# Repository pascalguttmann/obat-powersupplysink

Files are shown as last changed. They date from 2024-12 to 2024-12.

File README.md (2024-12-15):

# Obat - PowerSupplySink

KiCAD Project for the PowerSupplySink.

| TOP | BOT |
| --- | --- |
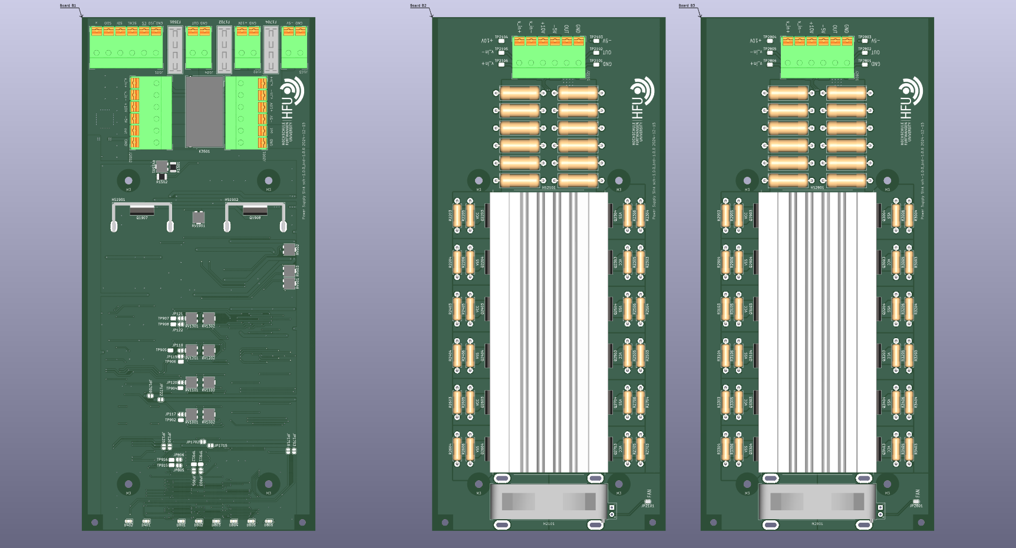
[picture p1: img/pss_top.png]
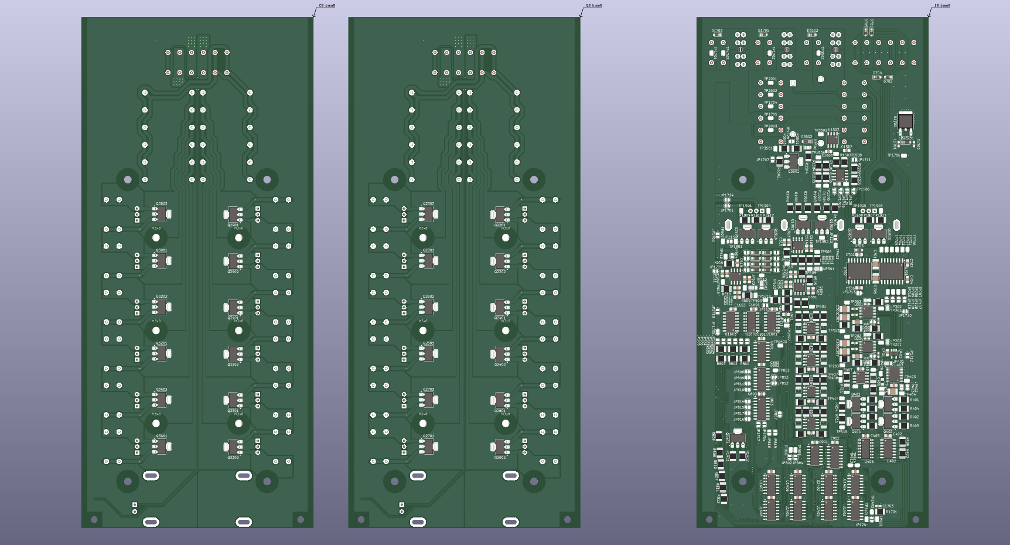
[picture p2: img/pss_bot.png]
|   |  |
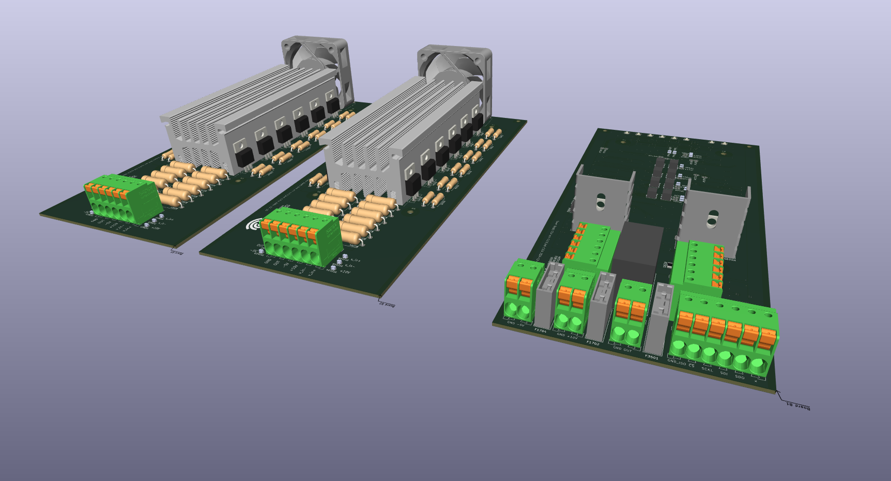
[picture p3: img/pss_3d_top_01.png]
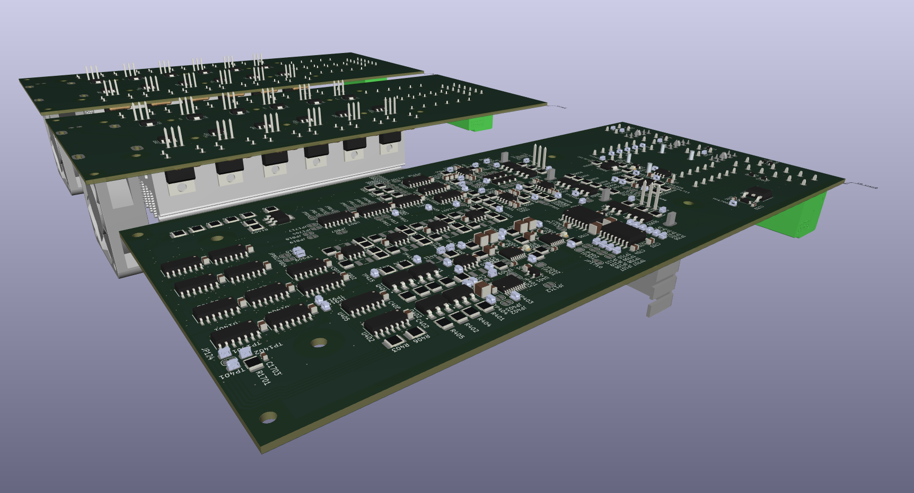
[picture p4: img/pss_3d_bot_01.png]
|  |  |
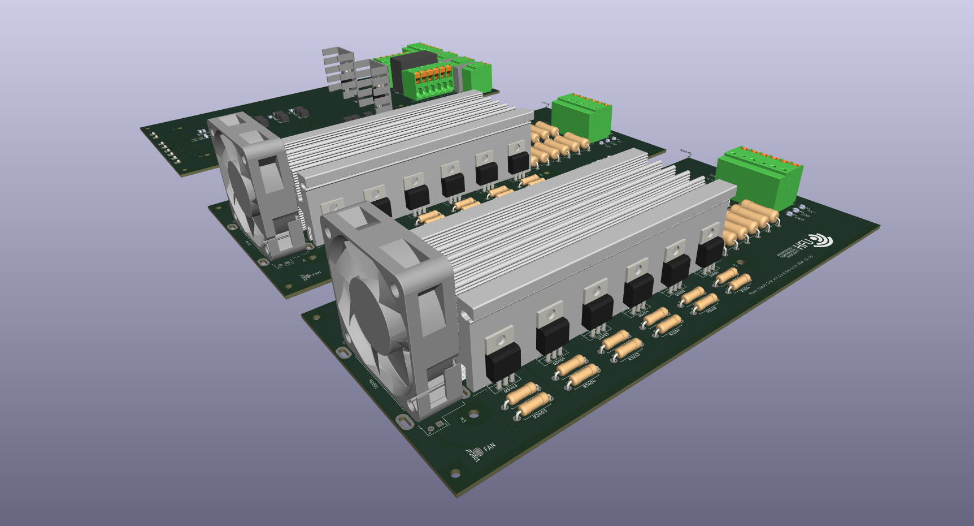
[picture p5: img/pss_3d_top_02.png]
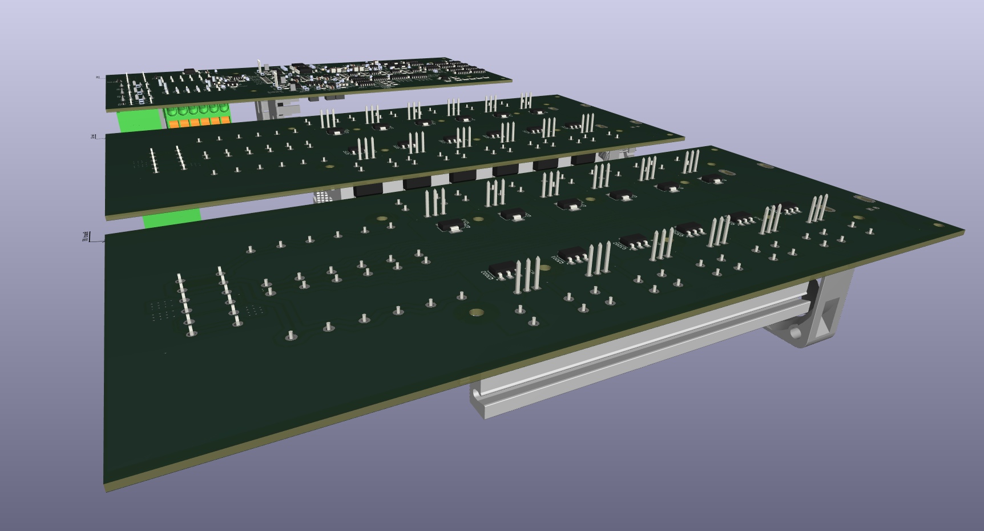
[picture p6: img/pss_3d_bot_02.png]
|  |  |

## License

This repository is licensed under the MIT license.

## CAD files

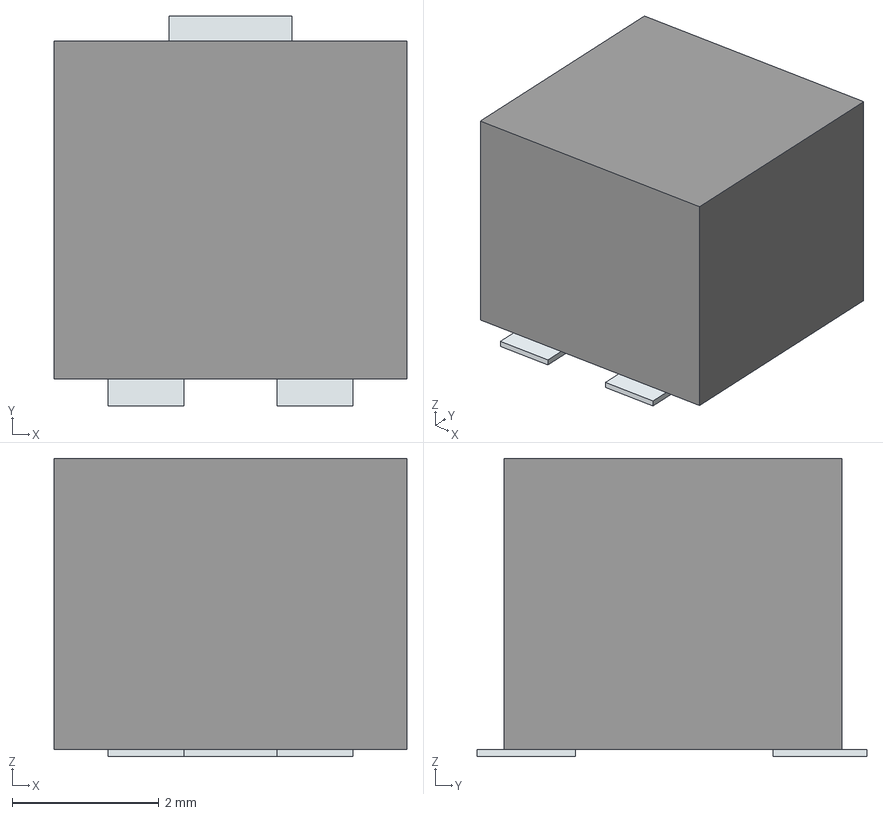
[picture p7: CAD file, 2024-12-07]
3d_models/PVG5H102C03R00.stp
4.80 x 5.31 x 4.06 mm
Pins

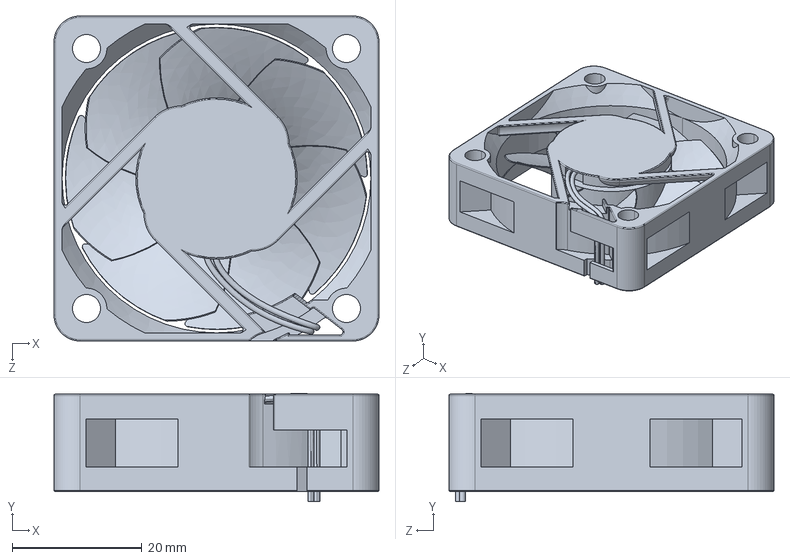
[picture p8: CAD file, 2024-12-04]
3d_models/Same_Sky_CFM-5015V-172-381.step
50.0 x 16.7 x 50.0 mm

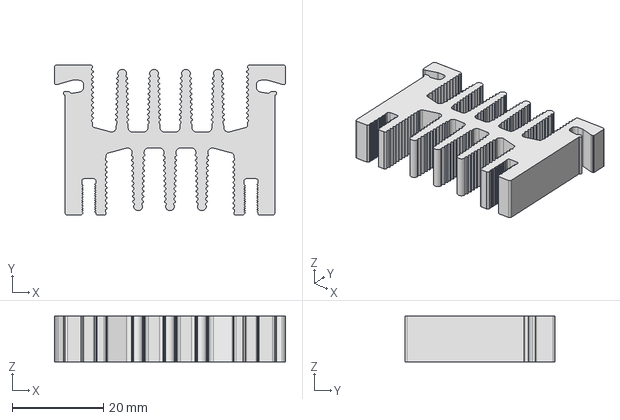
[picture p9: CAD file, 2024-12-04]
3d_models/sk499.stp
50.7 x 33.0 x 10.0 mm

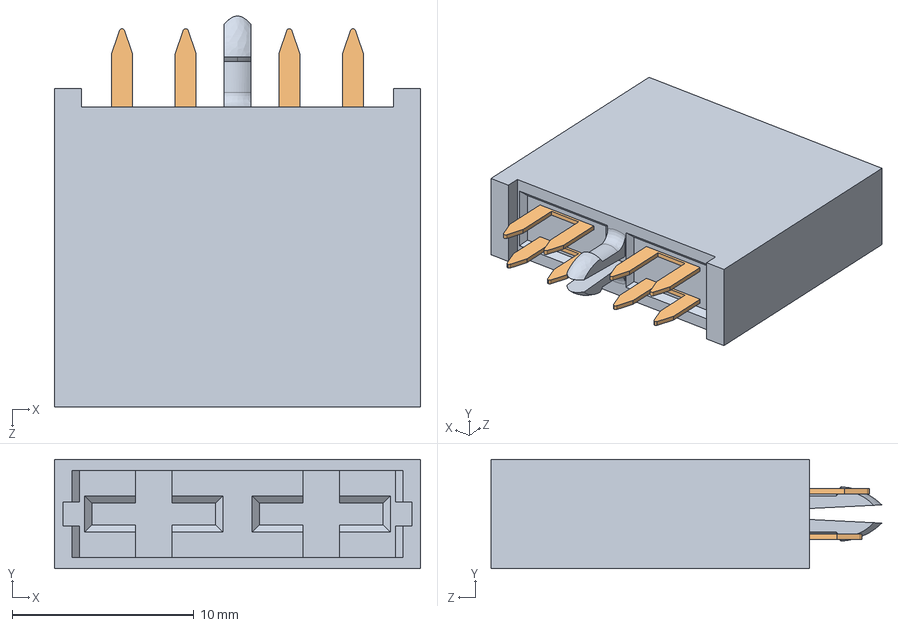
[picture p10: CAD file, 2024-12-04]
3d_models/178.6165.0000.step
20.1 x 6.00 x 21.5 mm

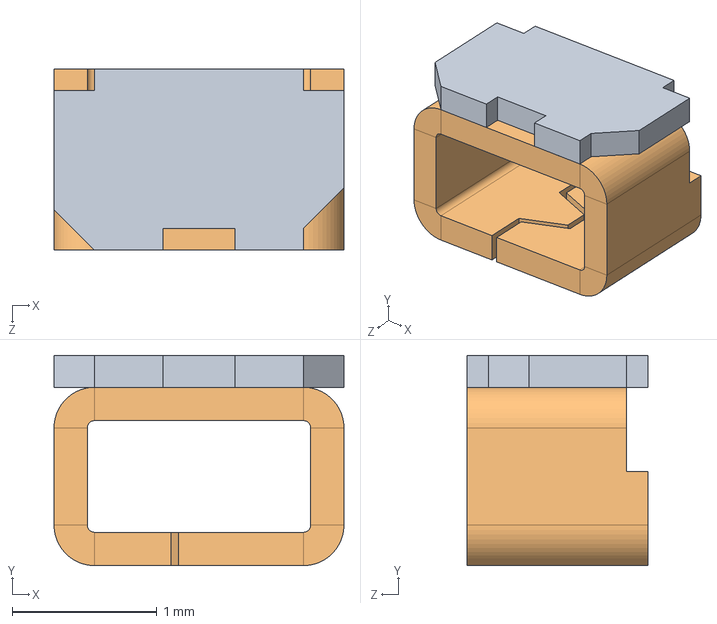
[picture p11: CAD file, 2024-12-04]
3d_models/RCTCTE.STEP
2.00 x 1.45 x 1.25 mm

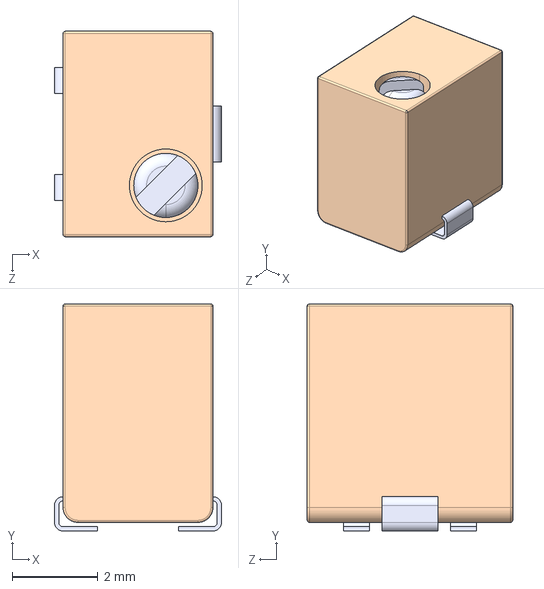
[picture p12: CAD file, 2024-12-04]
3d_models/PVG5A102C03B00.step
3.90 x 5.30 x 4.80 mm

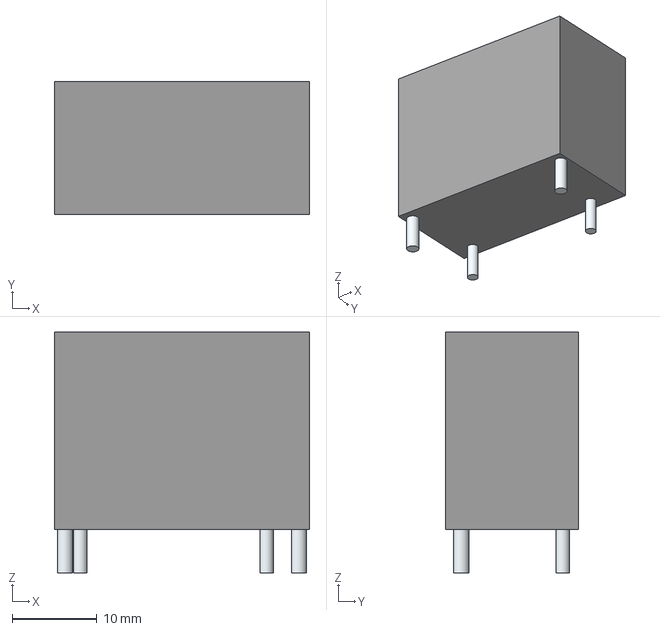
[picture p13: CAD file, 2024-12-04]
3d_models/ALFG2PF12.stp
30.1 x 15.7 x 28.4 mm
Leads x 4

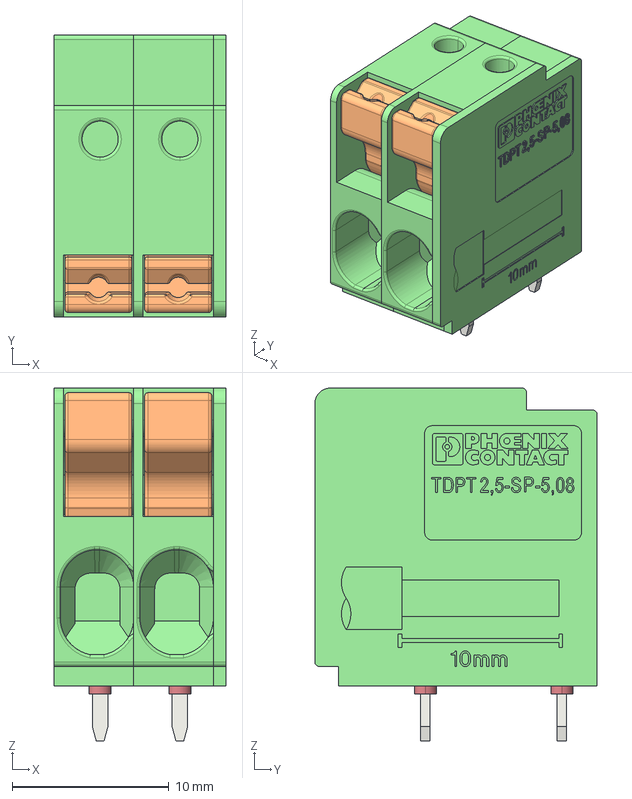
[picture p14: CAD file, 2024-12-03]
3d_models/pxc_1017503_00_00_TDPT-2-5-2-SP-5-08_3D.stp
11.0 x 18.0 x 22.5 mm
Bohrloch x 4
LP_TDPT_2_5_SP_DRST_vorne x 2
LP_TDPT_2_5_SP_DRST_hinten x 2
AC_TDPT_2_5_SP_pusher x 2
PK_TDPT_2_5_SP_GEH
PK_TDPT_2_5_SP_ENDGEH
DK_TDPT_2_5_SP

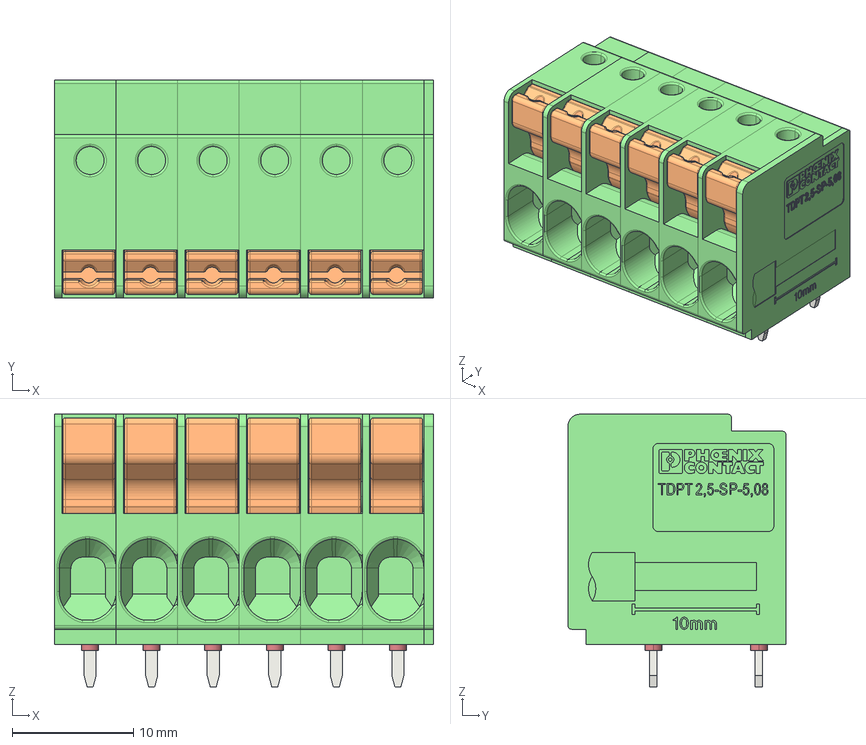
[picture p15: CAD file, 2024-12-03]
3d_models/pxc_1017507_00_00_TDPT-2-5-6-SP-5-08_3D.stp
31.3 x 18.0 x 22.5 mm
Bohrloch.2 x 12
LP_TDPT_2_5_SP_DRST_vorne.1 x 6
LP_TDPT_2_5_SP_DRST_hinten x 6
AC_TDPT_2_5_SP_pusher.1 x 6
PK_TDPT_2_5_SP_GEH x 5
PK_TDPT_2_5_SP_ENDGEH
DK_TDPT_2_5_SP

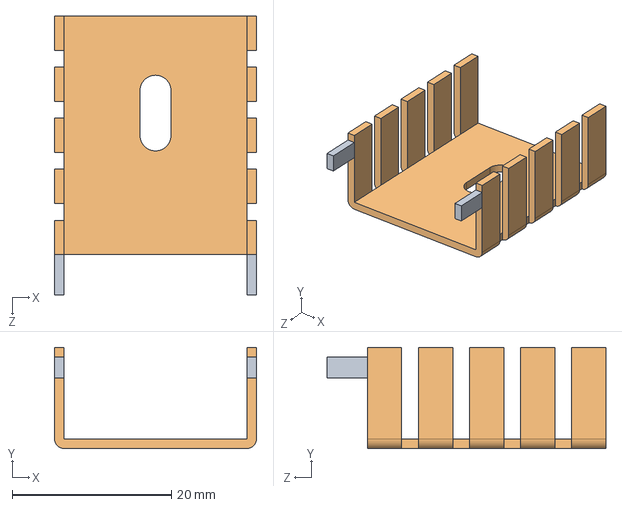
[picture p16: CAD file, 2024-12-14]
3d_models/575002B00000G.stp
25.4 x 12.7 x 35.0 mm

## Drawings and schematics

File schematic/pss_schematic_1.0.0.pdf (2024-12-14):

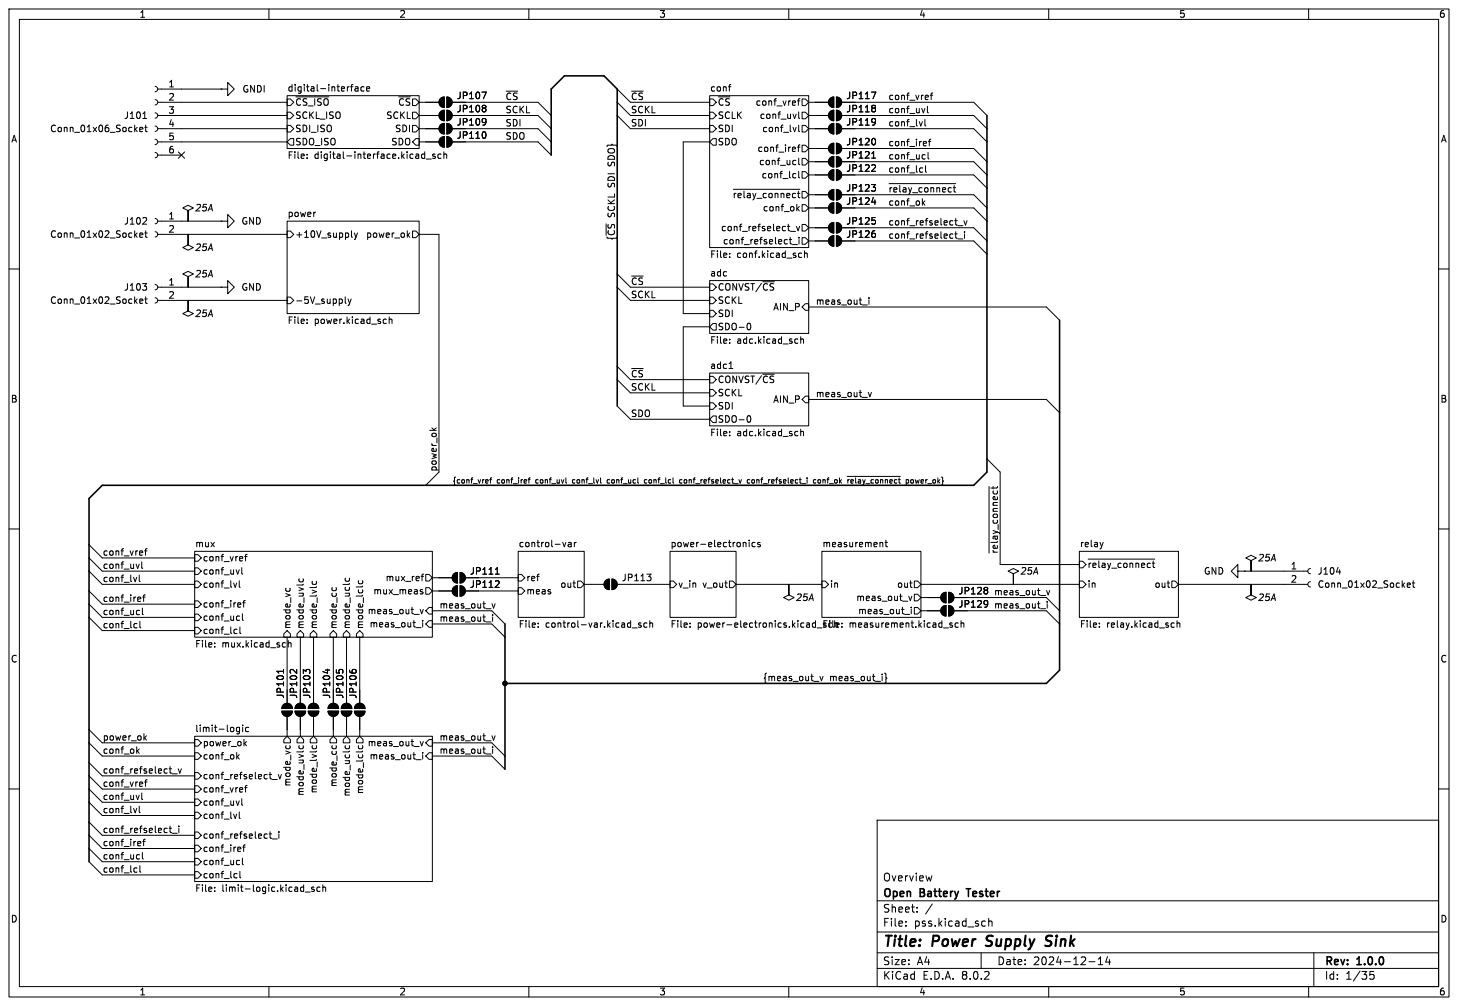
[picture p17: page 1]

SCKL SDI digital-interface File: digital-interface.kicad_sch
~{CS_ISO} SDI_ISO
SCKL_ISO

adc1 File: adc.kicad_sch AIN_P SDI CONVST/~{CS} SCKL SDO-0

ref control-var File: control-var.kicad_sch

v_in v_out power-electronics File: power-electronics.kicad_sch

limit-logic File: limit-logic.kicad_sch
conf_ok power_ok

Id: 1/35 Title: Power Supply Sink

3 REFIO 4 REFGND 5 REFCAP 6 AIN_P 7 AIN_GND 8 ~{RST} 9 GND GND GND

3 REFIO 4 REFGND 5 REFCAP 6 AIN_P 7 AIN_GND 8 ~{RST} 9 U201 ADS8665IPWR GND

1 SDI 10 CONVST/~{CS} 11 SCKL 12 SDO-0 13 ALARM/SDO-1/GPO 14 RVS 15 DVDD 16 AVDD

Id: 2/35 Title: Power Supply Sink

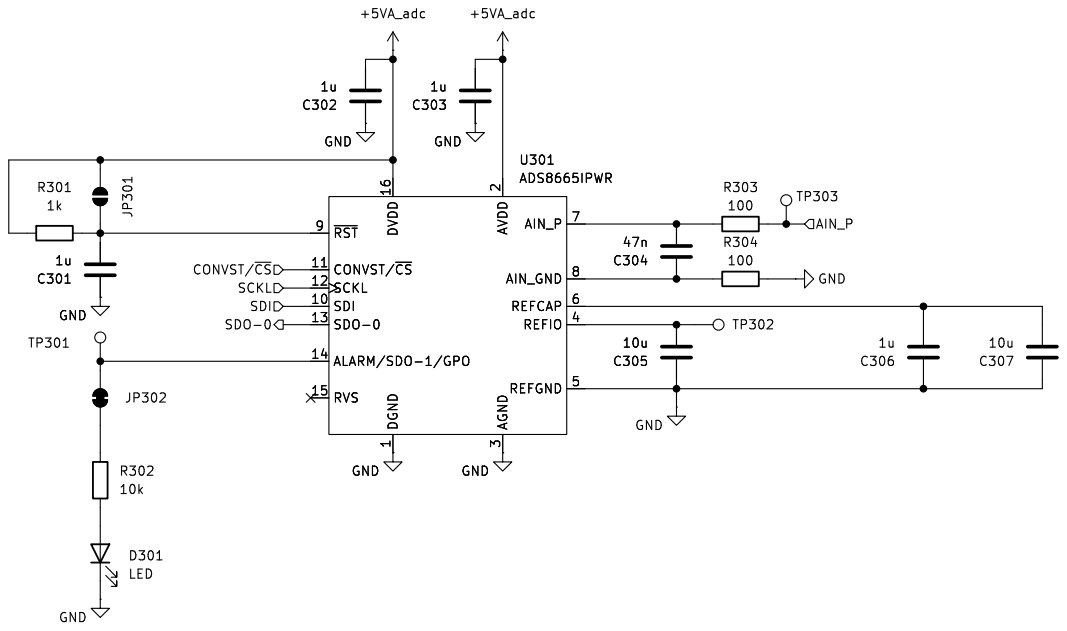
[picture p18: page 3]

3 REFIO 4 REFGND 5 REFCAP 6 AIN_P 7 AIN_GND 8 ~{RST} 9 GND GND

3 REFIO 4 REFGND 5 REFCAP 6 AIN_P 7 AIN_GND 8 ~{RST} 9 U301 ADS8665IPWR R303

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

Id: 3/35 Title: Power Supply Sink

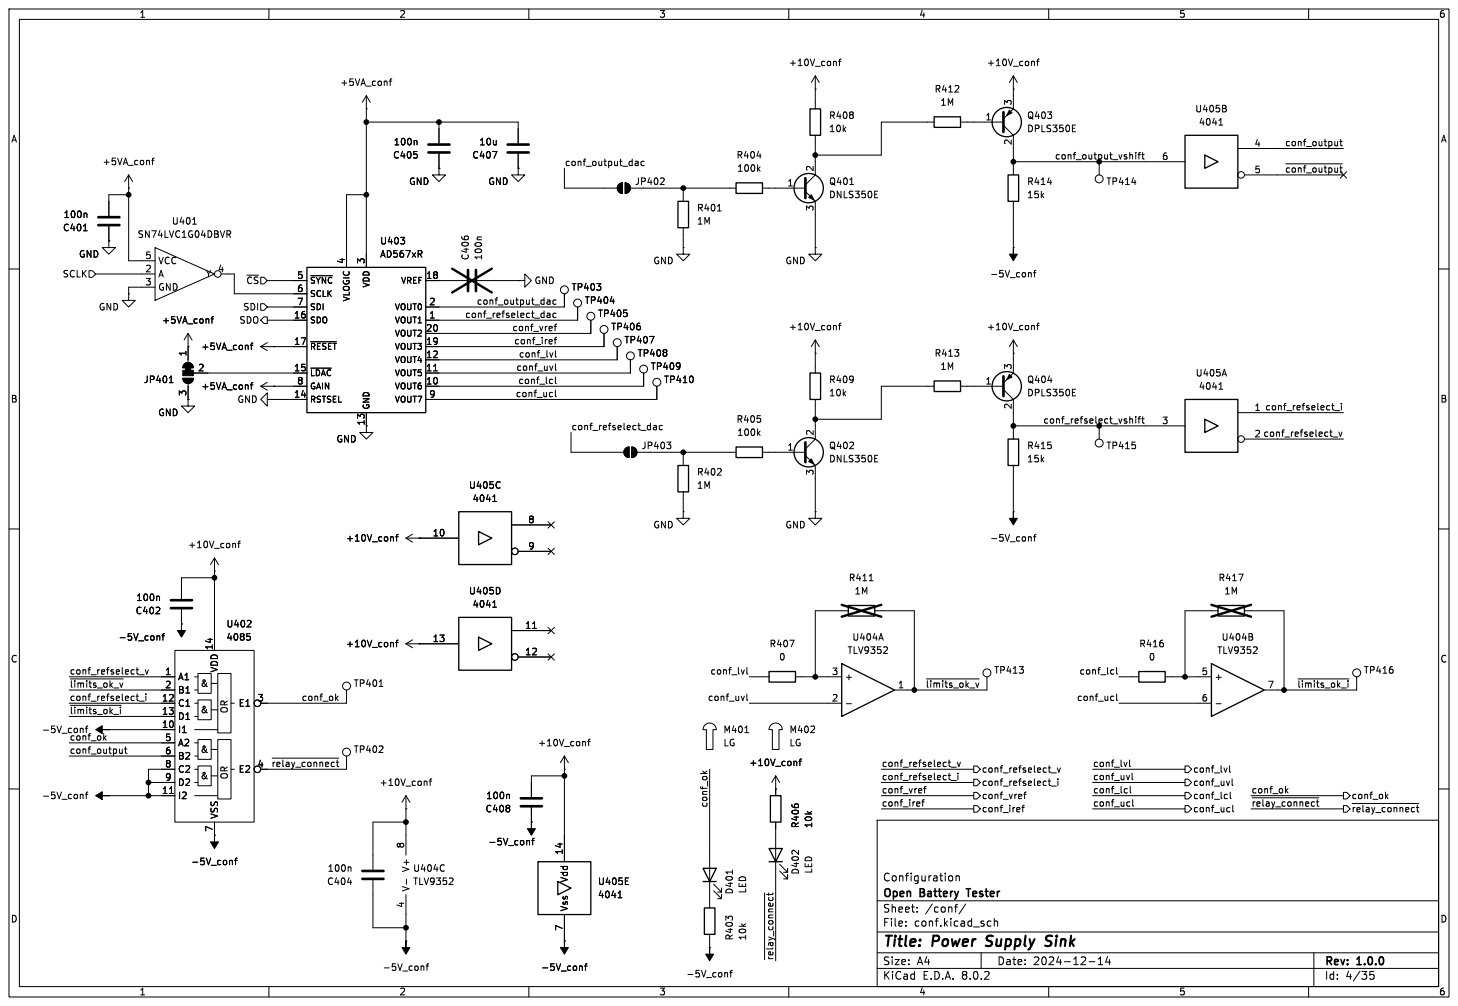
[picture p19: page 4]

Id: 4/35 Title: Power Supply Sink

diode-network File: diode-network.kicad_sch C518

Id: 5/35 Title: Power Supply Sink

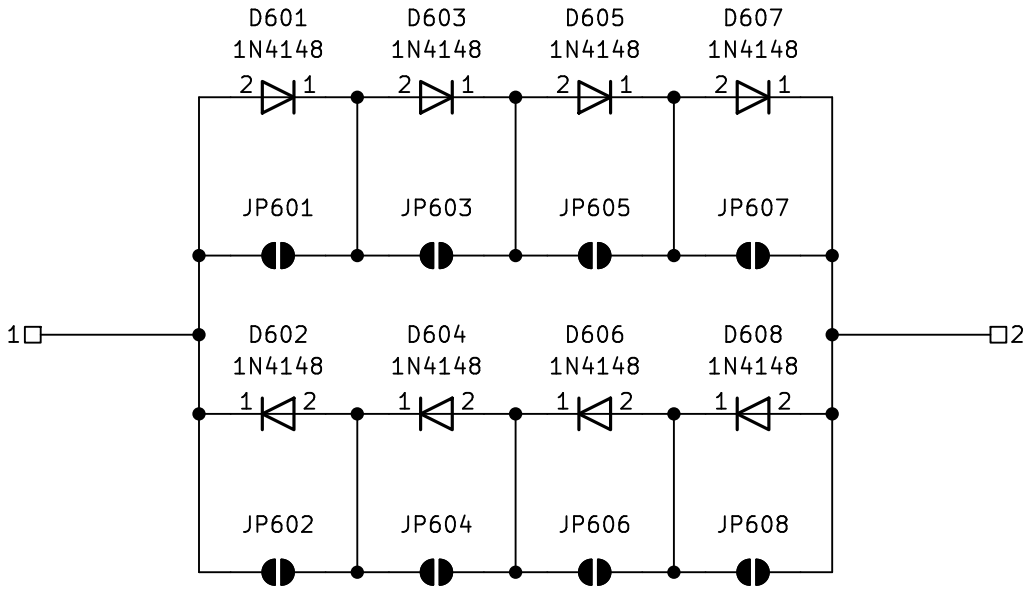
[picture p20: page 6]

Id: 6/35 Title: Power Supply Sink

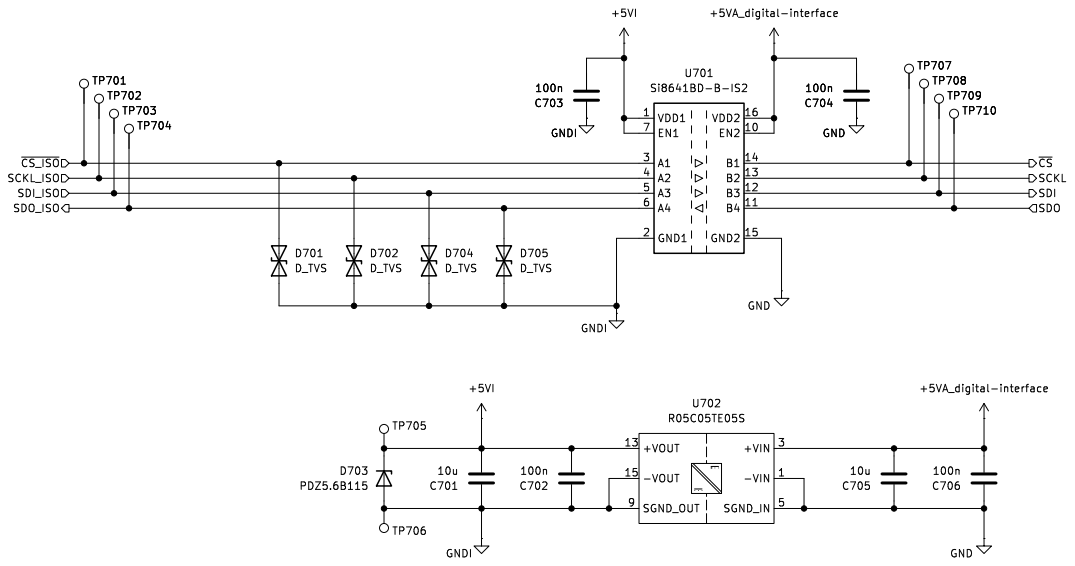
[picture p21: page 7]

File: digital-interface.kicad_sch Sheet: /digital-interface/
Id: 7/35 Title: Power Supply Sink

conf_refselect_i comp_mgtt comp_mstt mode-transition File: mode-transition.kicad_sch

conf_refselect_i compare-logic File: compare-logic.kicad_sch

File: limit-logic.kicad_sch Sheet: /limit-logic/
Id: 8/35 Title: Power Supply Sink

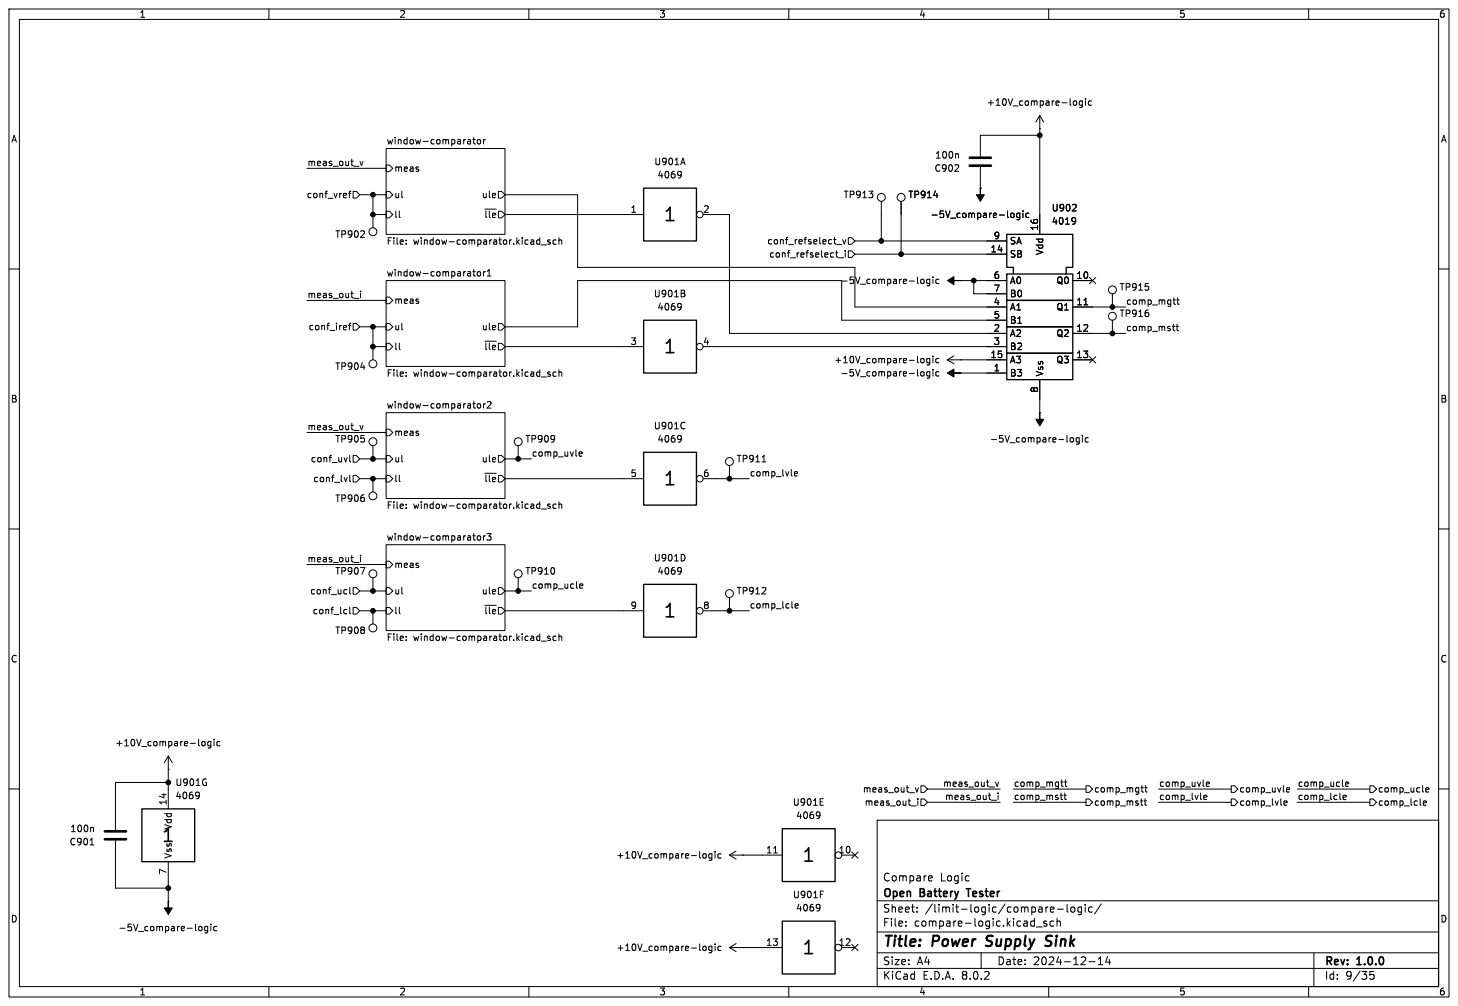
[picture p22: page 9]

llul window-comparator File: window-comparator.kicad_sch

llul window-comparator1 File: window-comparator.kicad_sch

llul window-comparator2 File: window-comparator.kicad_sch

llul window-comparator3 File: window-comparator.kicad_sch

File: compare-logic.kicad_sch Sheet: /limit-logic/compare-logic/
Id: 9/35 Title: Power Supply Sink

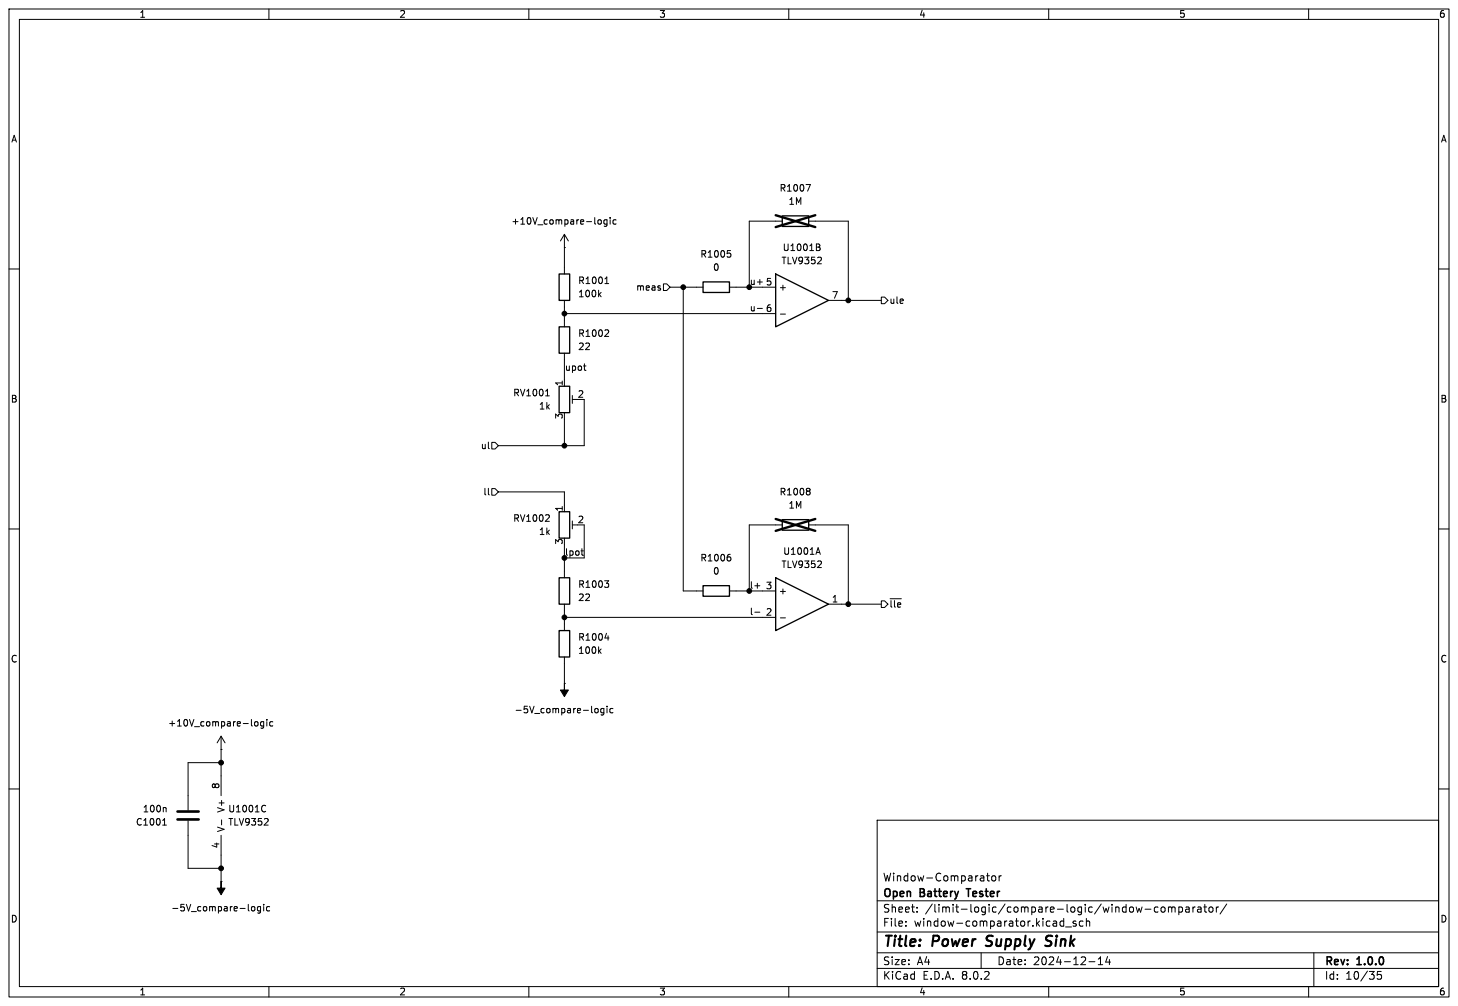
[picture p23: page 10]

File: window-comparator.kicad_sch Sheet: /limit-logic/compare-logic/window-comparator/
Id: 10/35 Title: Power Supply Sink

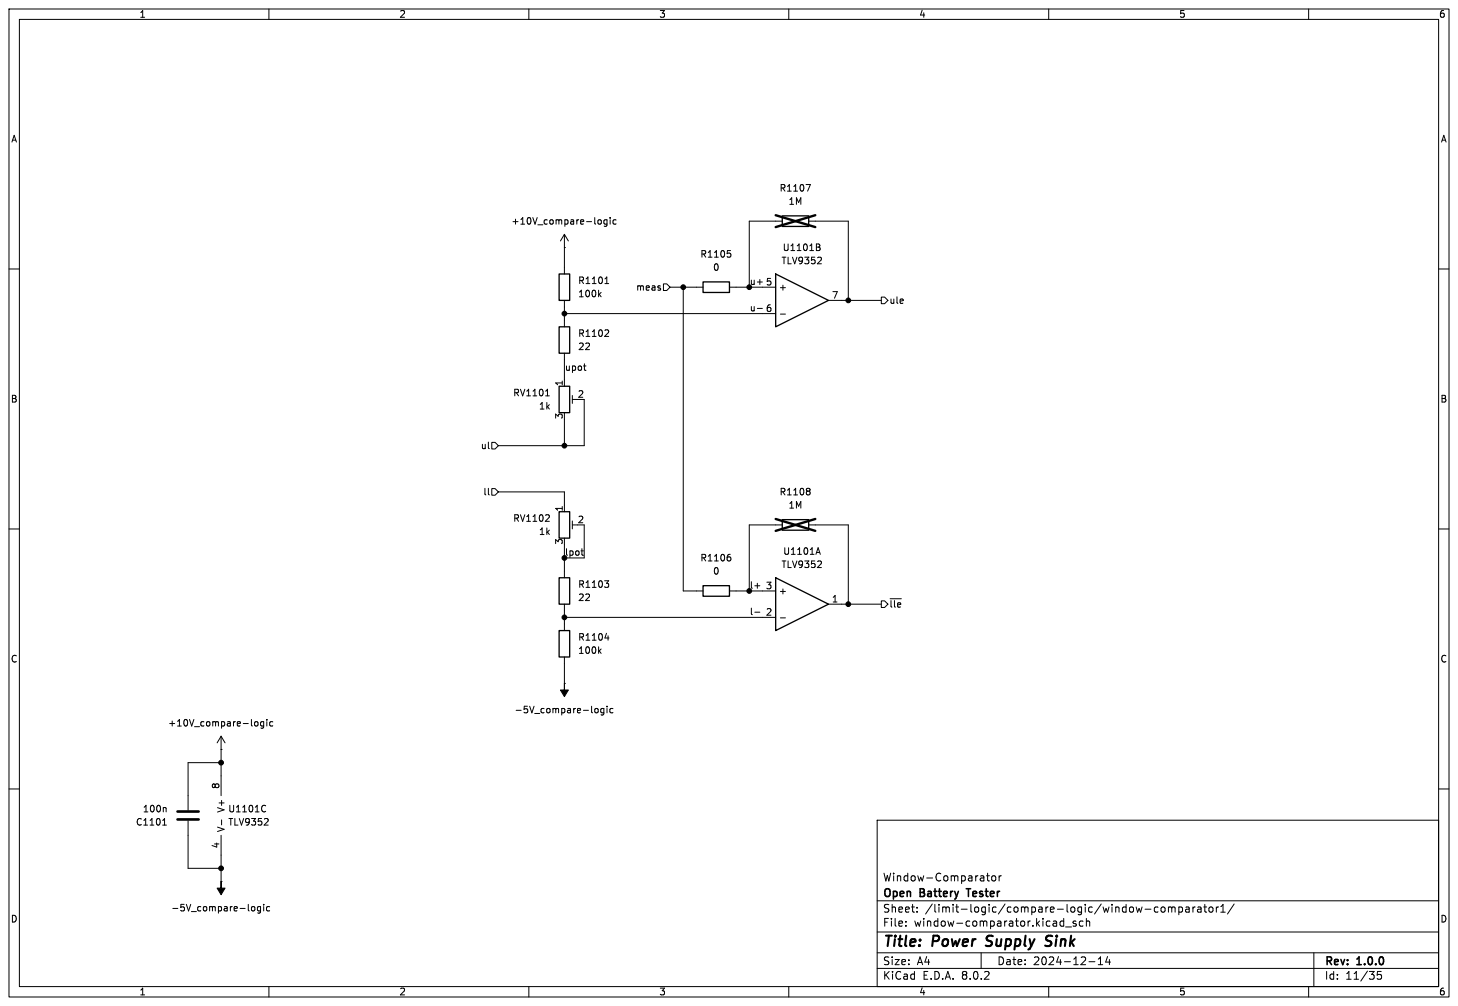
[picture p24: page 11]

File: window-comparator.kicad_sch Sheet: /limit-logic/compare-logic/window-comparator1/
Id: 11/35 Title: Power Supply Sink

File: window-comparator.kicad_sch Sheet: /limit-logic/compare-logic/window-comparator2/
Id: 12/35 Title: Power Supply Sink

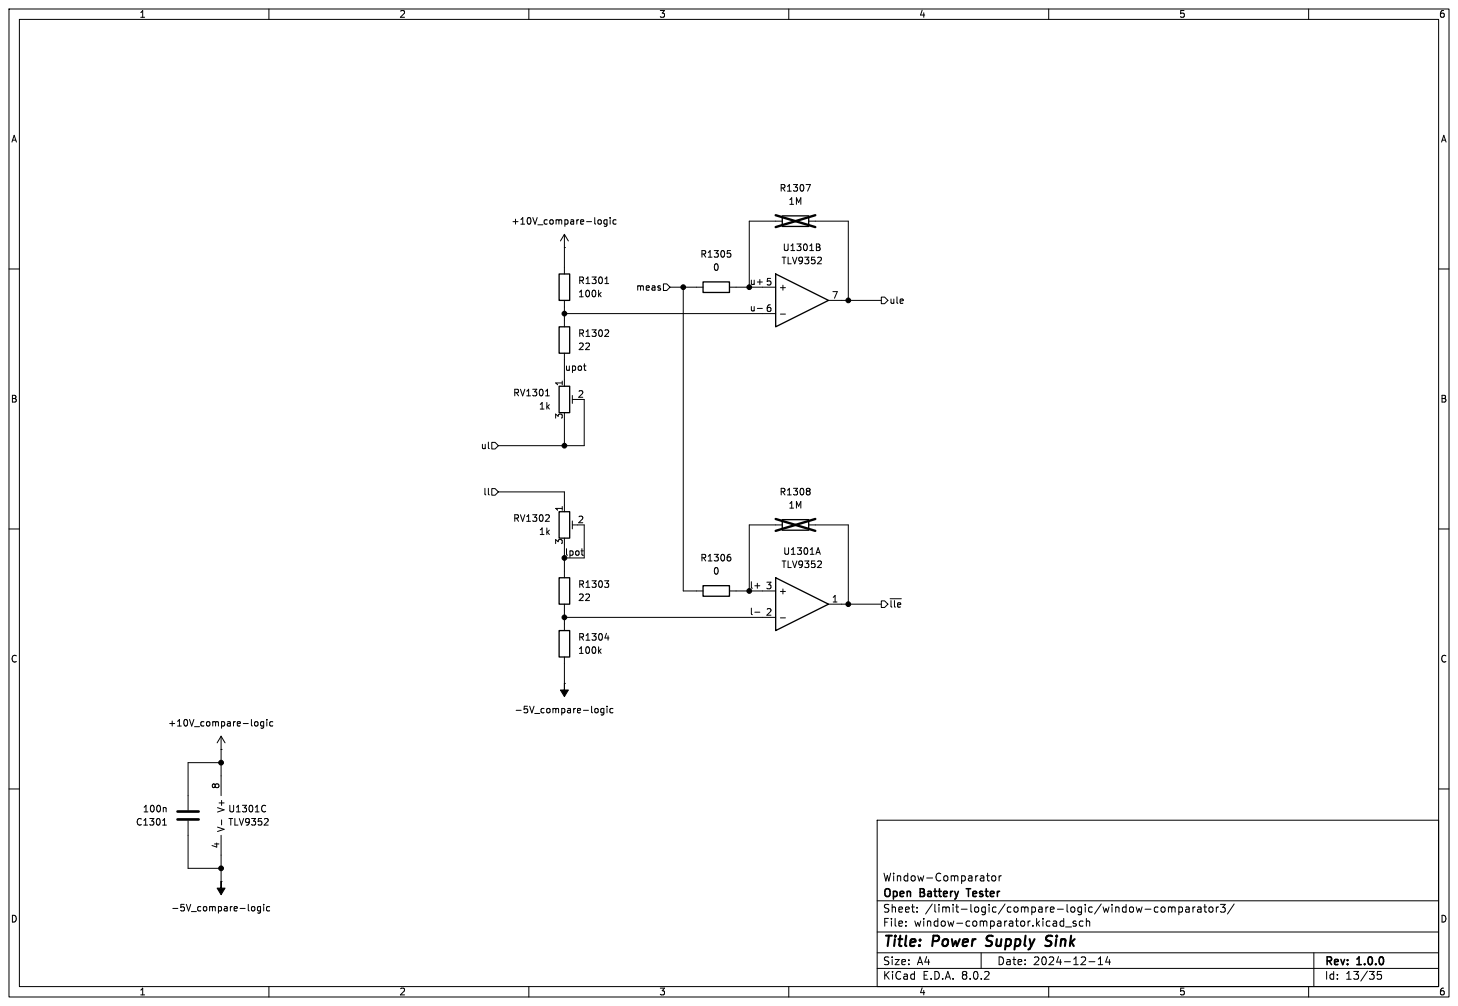
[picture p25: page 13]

File: window-comparator.kicad_sch Sheet: /limit-logic/compare-logic/window-comparator3/
Id: 13/35 Title: Power Supply Sink

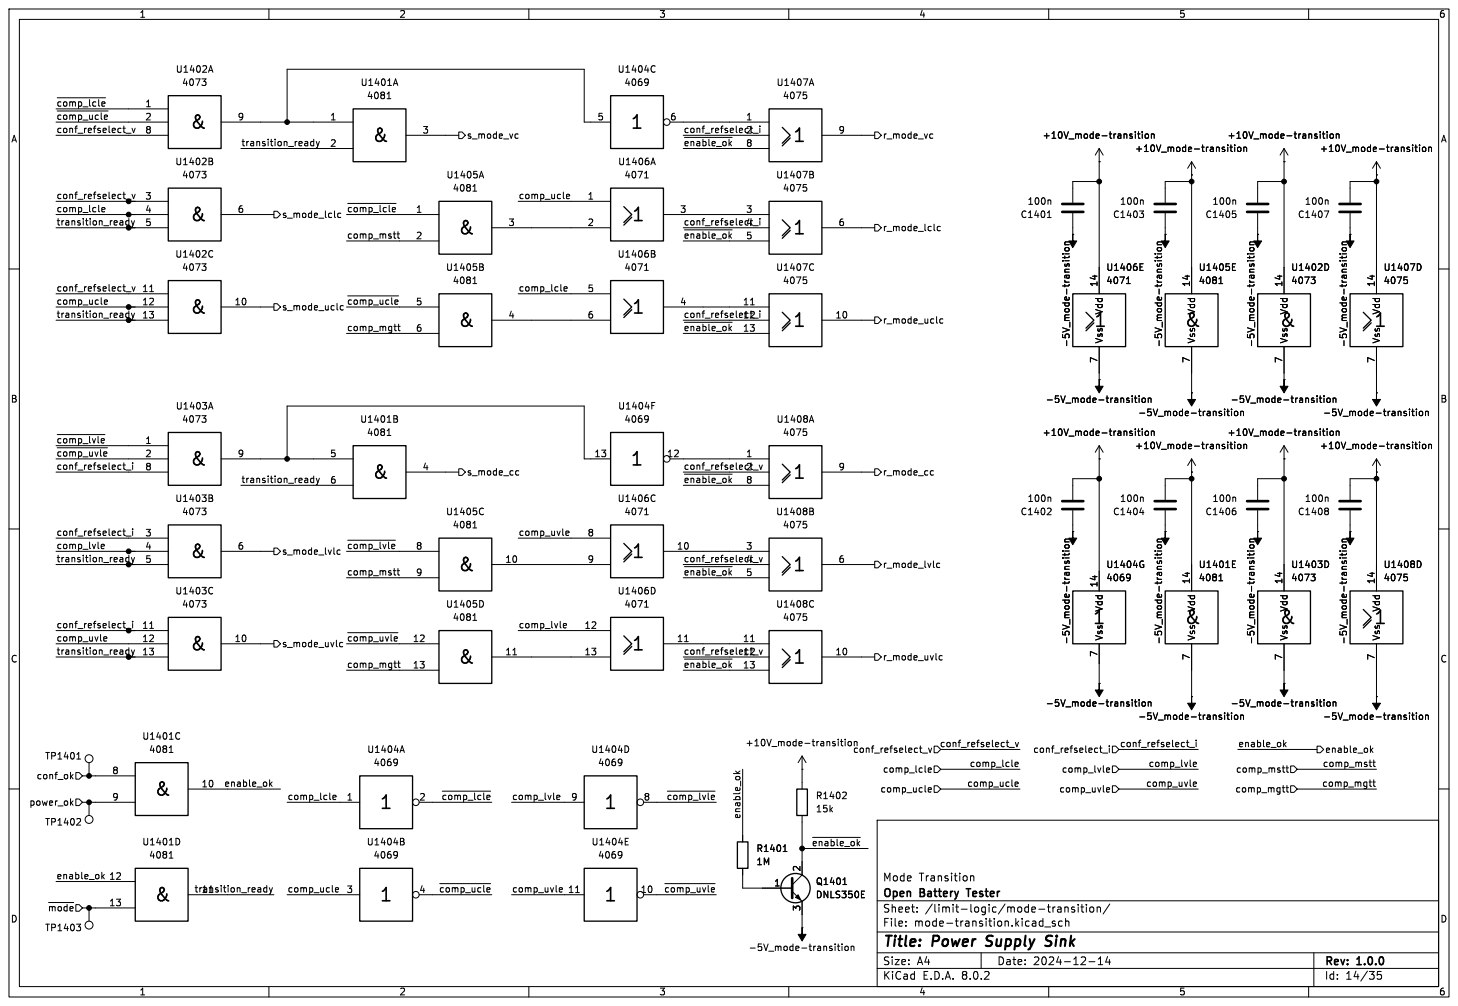
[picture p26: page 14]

File: mode-transition.kicad_sch Sheet: /limit-logic/mode-transition/
Id: 14/35 Title: Power Supply Sink

Id: 15/35 Title: Power Supply Sink

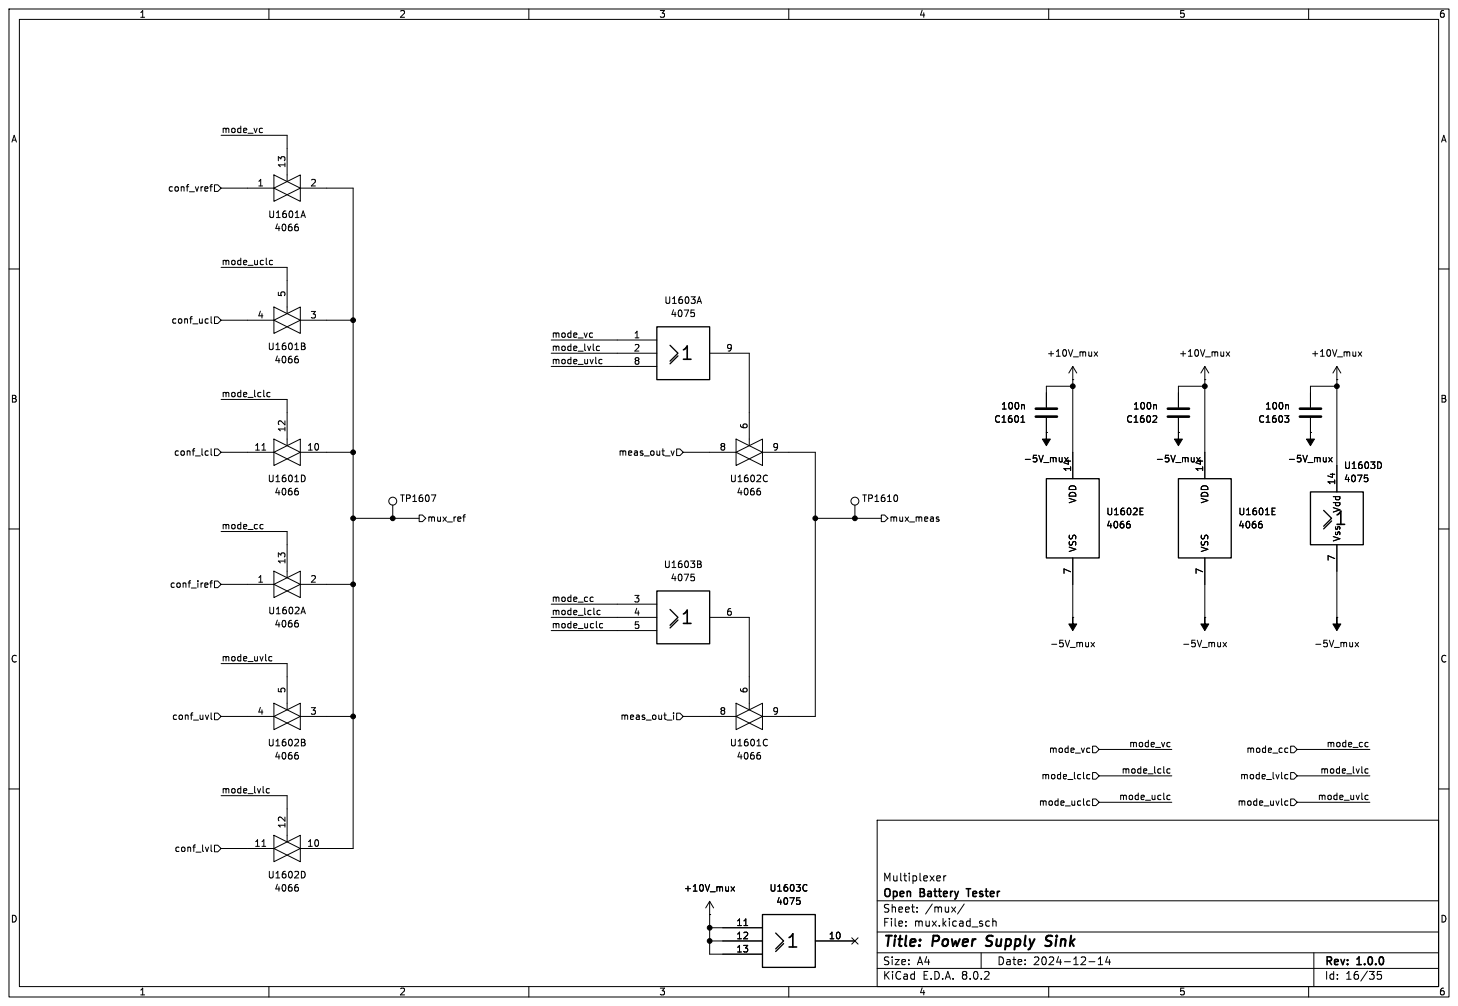
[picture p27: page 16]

Id: 16/35 Title: Power Supply Sink

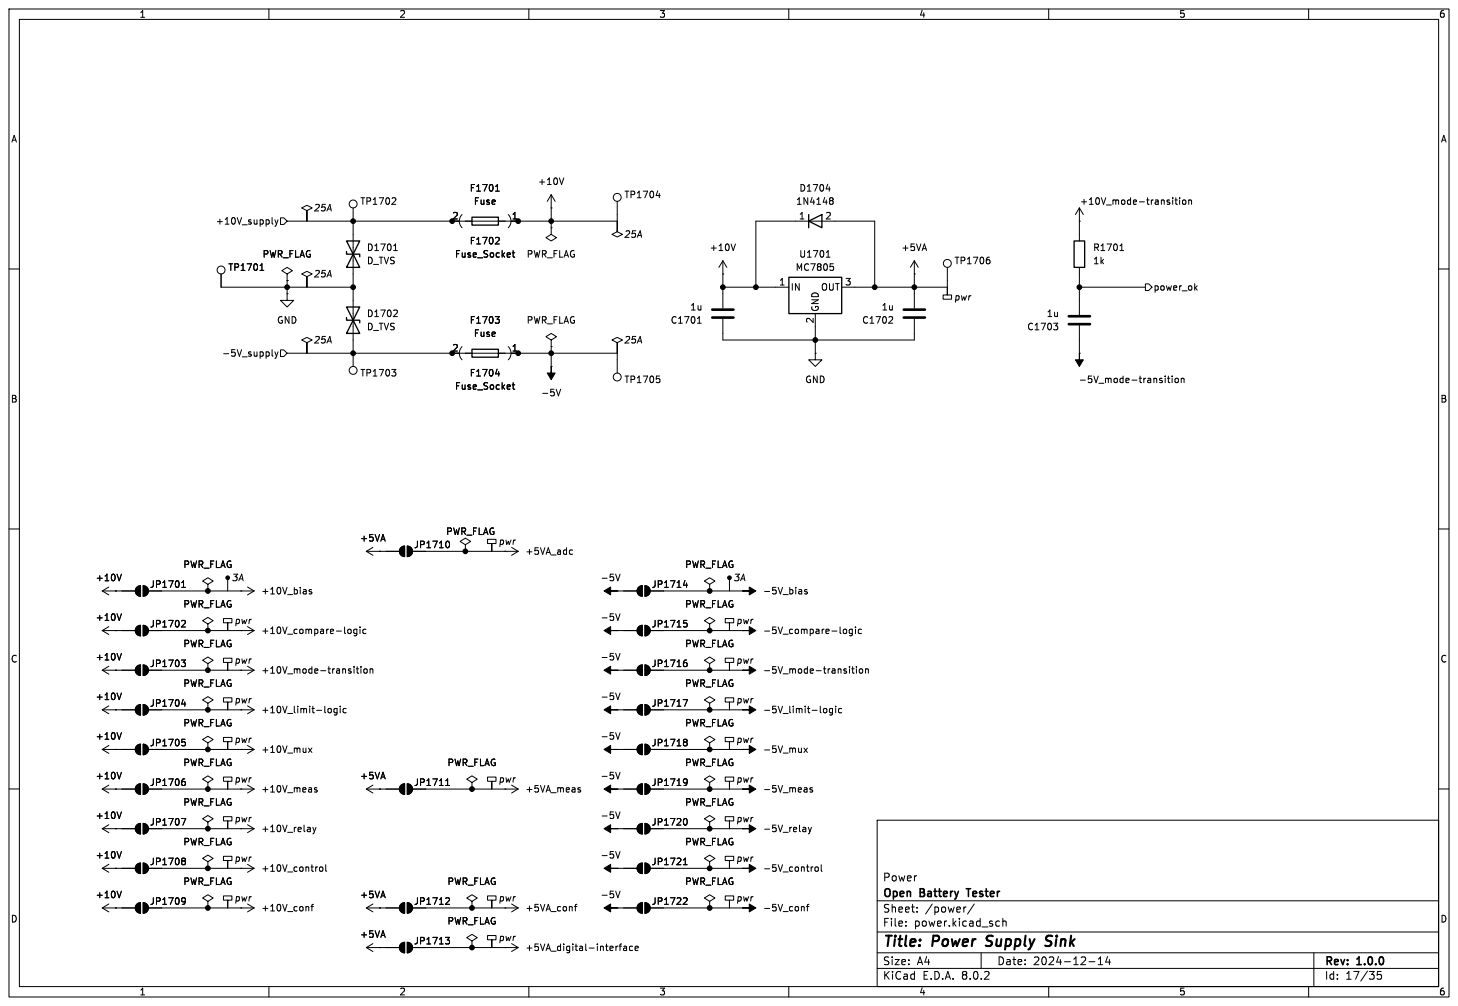
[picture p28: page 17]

File: power.kicad_sch Sheet: /power/
Id: 17/35 Title: Power Supply Sink

File: power-electronics.kicad_sch Sheet: /power-electronics/
Id: 18/35 Title: Power Supply Sink


File: bias.kicad_sch Sheet: /power-electronics/bias/
Id: 19/35 Title: Power Supply Sink


File: outstage.kicad_sch Sheet: /power-electronics/outstage/
Id: 20/35 Title: Power Supply Sink

File: outstage-unit.kicad_sch Sheet: /power-electronics/outstage/outstage-unit/
Id: 21/35 Title: Power Supply Sink


File: emitter_follower.kicad_sch Sheet: /power-electronics/outstage/outstage-unit/emitter_follower1/
Id: 22/35 Title: Power Supply Sink


File: emitter_follower.kicad_sch Sheet: /power-electronics/outstage/outstage-unit/emitter_follower2/
Id: 23/35 Title: Power Supply Sink

File: emitter_follower.kicad_sch Sheet: /power-electronics/outstage/outstage-unit/emitter_follower3/
Id: 24/35 Title: Power Supply Sink


File: emitter_follower.kicad_sch Sheet: /power-electronics/outstage/outstage-unit/emitter_follower4/
Id: 25/35 Title: Power Supply Sink


File: emitter_follower.kicad_sch Sheet: /power-electronics/outstage/outstage-unit/emitter_follower5/
Id: 26/35 Title: Power Supply Sink


File: emitter_follower.kicad_sch Sheet: /power-electronics/outstage/outstage-unit/emitter_follower6/
Id: 27/35 Title: Power Supply Sink

File: outstage-unit.kicad_sch Sheet: /power-electronics/outstage/outstage-unit1/
Id: 28/35 Title: Power Supply Sink


File: emitter_follower.kicad_sch Sheet: /power-electronics/outstage/outstage-unit1/emitter_follower1/
Id: 29/35 Title: Power Supply Sink

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

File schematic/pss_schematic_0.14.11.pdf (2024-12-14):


SCKL SDI digital-interface File: digital-interface.kicad_sch
~{CS_ISO} SDI_ISO
SCKL_ISO

adc1 File: adc.kicad_sch AIN_P SDI CONVST/~{CS} SCKL SDO-0

ref control-var File: control-var.kicad_sch

v_in v_out power-electronics File: power-electronics.kicad_sch

limit-logic File: limit-logic.kicad_sch
conf_ok power_ok

Id: 1/35 Title: Power Supply Sink

3 REFIO 4 REFGND 5 REFCAP 6 AIN_P 7 AIN_GND 8 ~{RST} 9 U201 ADS8665IPWR GND

1 SDI 10 CONVST/~{CS} 11 SCKL 12 SDO-0 13 ALARM/SDO-1/GPO 14 RVS 15 DVDD 16 AVDD

3 REFIO 4 REFGND 5 REFCAP 6 AIN_P 7 AIN_GND 8 ~{RST} 9 GND

Id: 2/35 Title: Power Supply Sink


3 REFIO 4 REFGND 5 REFCAP 6 AIN_P 7 AIN_GND 8 ~{RST} 9 U301 ADS8665IPWR

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

3 REFIO 4 REFGND 5 REFCAP 6 AIN_P 7 AIN_GND 8 ~{RST} 9 GND

Id: 3/35 Title: Power Supply Sink


Id: 4/35 Title: Power Supply Sink

diode-network File: diode-network.kicad_sch R510

Id: 5/35 Title: Power Supply Sink


Id: 6/35 Title: Power Supply Sink


File: digital-interface.kicad_sch Sheet: /digital-interface/
Id: 7/35 Title: Power Supply Sink

conf_refselect_i comp_mgtt comp_mstt mode-transition File: mode-transition.kicad_sch
s_mode_cc enable_ok

conf_refselect_i compare-logic File: compare-logic.kicad_sch

File: limit-logic.kicad_sch Sheet: /limit-logic/
Id: 8/35 Title: Power Supply Sink


llul window-comparator File: window-comparator.kicad_sch C901

llul window-comparator1 File: window-comparator.kicad_sch

llul window-comparator2 File: window-comparator.kicad_sch

llul window-comparator3 File: window-comparator.kicad_sch

File: compare-logic.kicad_sch Sheet: /limit-logic/compare-logic/
Id: 9/35 Title: Power Supply Sink


File: window-comparator.kicad_sch Sheet: /limit-logic/compare-logic/window-comparator/
Id: 10/35 Title: Power Supply Sink


File: window-comparator.kicad_sch Sheet: /limit-logic/compare-logic/window-comparator1/
Id: 11/35 Title: Power Supply Sink

File: window-comparator.kicad_sch Sheet: /limit-logic/compare-logic/window-comparator2/
Id: 12/35 Title: Power Supply Sink


File: window-comparator.kicad_sch Sheet: /limit-logic/compare-logic/window-comparator3/
Id: 13/35 Title: Power Supply Sink


4075 Vdd 14 Vss 7 +10V_mode-transition +10V_mode-transition

File: mode-transition.kicad_sch Sheet: /limit-logic/mode-transition/
Id: 14/35 Title: Power Supply Sink

Id: 15/35 Title: Power Supply Sink


Id: 16/35 Title: Power Supply Sink


File: power.kicad_sch Sheet: /power/
Id: 17/35 Title: Power Supply Sink

File: power-electronics.kicad_sch Sheet: /power-electronics/
Id: 18/35 Title: Power Supply Sink


File: bias.kicad_sch Sheet: /power-electronics/bias/
Id: 19/35 Title: Power Supply Sink


File: outstage.kicad_sch Sheet: /power-electronics/outstage/
Id: 20/35 Title: Power Supply Sink

File: outstage-unit.kicad_sch Sheet: /power-electronics/outstage/outstage-unit/
Id: 21/35 Title: Power Supply Sink


File: emitter_follower.kicad_sch Sheet: /power-electronics/outstage/outstage-unit/emitter_follower1/
Id: 22/35 Title: Power Supply Sink


File: emitter_follower.kicad_sch Sheet: /power-electronics/outstage/outstage-unit/emitter_follower2/
Id: 23/35 Title: Power Supply Sink

File: emitter_follower.kicad_sch Sheet: /power-electronics/outstage/outstage-unit/emitter_follower3/
Id: 24/35 Title: Power Supply Sink


File: emitter_follower.kicad_sch Sheet: /power-electronics/outstage/outstage-unit/emitter_follower4/
Id: 25/35 Title: Power Supply Sink


File: emitter_follower.kicad_sch Sheet: /power-electronics/outstage/outstage-unit/emitter_follower5/
Id: 26/35 Title: Power Supply Sink


File: emitter_follower.kicad_sch Sheet: /power-electronics/outstage/outstage-unit/emitter_follower6/
Id: 27/35 Title: Power Supply Sink

File: outstage-unit.kicad_sch Sheet: /power-electronics/outstage/outstage-unit1/
Id: 28/35 Title: Power Supply Sink


File: emitter_follower.kicad_sch Sheet: /power-electronics/outstage/outstage-unit1/emitter_follower1/
Id: 29/35 Title: Power Supply Sink

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

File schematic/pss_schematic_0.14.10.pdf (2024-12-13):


SCKL SDI digital-interface File: digital-interface.kicad_sch
~{CS_ISO} SDI_ISO
SCKL_ISO

adc1 File: adc.kicad_sch AIN_P SDI CONVST/~{CS} SCKL SDO-0

ref control-var File: control-var.kicad_sch

v_in v_out power-electronics File: power-electronics.kicad_sch

limit-logic File: limit-logic.kicad_sch
conf_ok power_ok

Id: 1/35 Title: Power Supply Sink

3 REFIO 4 REFGND 5 REFCAP 6 AIN_P 7 AIN_GND 8 ~{RST} 9GND

3 REFIO 4 REFGND 5 REFCAP 6 AIN_P 7 AIN_GND 8 ~{RST} 9 U201 ADS8665IPWR

1 SDI 10 CONVST/~{CS} 11 SCKL 12 SDO-0 13 ALARM/SDO-1/GPO 14 RVS 15 DVDD 16 AVDD

Id: 2/35 Title: Power Supply Sink


3 REFIO 4 REFGND 5 REFCAP 6 AIN_P 7 AIN_GND 8 ~{RST} 9 U301 ADS8665IPWR GND GND

3 REFIO 4 REFGND 5 REFCAP 6 AIN_P 7 AIN_GND 8 ~{RST} 9 GND GND

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

Id: 3/35 Title: Power Supply Sink


Id: 4/35 Title: Power Supply Sink

diode-network File: diode-network.kicad_sch R510

Id: 5/35 Title: Power Supply Sink


Id: 6/35 Title: Power Supply Sink


File: digital-interface.kicad_sch Sheet: /digital-interface/
Id: 7/35 Title: Power Supply Sink

conf_refselect_i compare-logic File: compare-logic.kicad_sch
conf_vref conf_refselect_v

File: limit-logic.kicad_sch Sheet: /limit-logic/
Id: 8/35 Title: Power Supply Sink


llul window-comparator File: window-comparator.kicad_sch

llul window-comparator1 File: window-comparator.kicad_sch

llul window-comparator2 File: window-comparator.kicad_sch

llul window-comparator3 File: window-comparator.kicad_sch

File: compare-logic.kicad_sch Sheet: /limit-logic/compare-logic/
Id: 9/35 Title: Power Supply Sink


File: window-comparator.kicad_sch Sheet: /limit-logic/compare-logic/window-comparator/
Id: 10/35 Title: Power Supply Sink


File: window-comparator.kicad_sch Sheet: /limit-logic/compare-logic/window-comparator1/
Id: 11/35 Title: Power Supply Sink

File: window-comparator.kicad_sch Sheet: /limit-logic/compare-logic/window-comparator2/
Id: 12/35 Title: Power Supply Sink


File: window-comparator.kicad_sch Sheet: /limit-logic/compare-logic/window-comparator3/
Id: 13/35 Title: Power Supply Sink


File: mode-transition.kicad_sch Sheet: /limit-logic/mode-transition/
Id: 14/35 Title: Power Supply Sink

Id: 15/35 Title: Power Supply Sink


Id: 16/35 Title: Power Supply Sink


File: power.kicad_sch Sheet: /power/
Id: 17/35 Title: Power Supply Sink

File: power-electronics.kicad_sch Sheet: /power-electronics/
Id: 18/35 Title: Power Supply Sink


File: bias.kicad_sch Sheet: /power-electronics/bias/
Id: 19/35 Title: Power Supply Sink


File: outstage.kicad_sch Sheet: /power-electronics/outstage/
Id: 20/35 Title: Power Supply Sink

File: outstage-unit.kicad_sch Sheet: /power-electronics/outstage/outstage-unit/
Id: 21/35 Title: Power Supply Sink


File: emitter_follower.kicad_sch Sheet: /power-electronics/outstage/outstage-unit/emitter_follower1/
Id: 22/35 Title: Power Supply Sink


File: emitter_follower.kicad_sch Sheet: /power-electronics/outstage/outstage-unit/emitter_follower2/
Id: 23/35 Title: Power Supply Sink

File: emitter_follower.kicad_sch Sheet: /power-electronics/outstage/outstage-unit/emitter_follower3/
Id: 24/35 Title: Power Supply Sink


File: emitter_follower.kicad_sch Sheet: /power-electronics/outstage/outstage-unit/emitter_follower4/
Id: 25/35 Title: Power Supply Sink


File: emitter_follower.kicad_sch Sheet: /power-electronics/outstage/outstage-unit/emitter_follower5/
Id: 26/35 Title: Power Supply Sink


File: emitter_follower.kicad_sch Sheet: /power-electronics/outstage/outstage-unit/emitter_follower6/
Id: 27/35 Title: Power Supply Sink

File: outstage-unit.kicad_sch Sheet: /power-electronics/outstage/outstage-unit1/
Id: 28/35 Title: Power Supply Sink


File: emitter_follower.kicad_sch Sheet: /power-electronics/outstage/outstage-unit1/emitter_follower1/
Id: 29/35 Title: Power Supply Sink


File: emitter_follower.kicad_sch Sheet: /power-electronics/outstage/outstage-unit1/emitter_follower2/
Id: 30/35 Title: Power Supply Sink
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

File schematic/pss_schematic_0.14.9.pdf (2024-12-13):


SCKL SDI digital-interface File: digital-interface.kicad_sch
~{CS_ISO} SDI_ISO
SCKL_ISO

adc1 File: adc.kicad_sch AIN_P SDI CONVST/~{CS} SCKL SDO-0

ref control-var File: control-var.kicad_sch

v_in v_out power-electronics File: power-electronics.kicad_sch

limit-logic File: limit-logic.kicad_sch
conf_ok power_ok

Id: 1/35 Title: Power Supply Sink

3 REFIO 4 REFGND 5 REFCAP 6 AIN_P 7 AIN_GND 8 ~{RST} 9 GND

3 REFIO 4 REFGND 5 REFCAP 6 AIN_P 7 AIN_GND 8 ~{RST} 9 U201 ADS8665IPWR R203

1 SDI 10 CONVST/~{CS} 11 SCKL 12 SDO-0 13 ALARM/SDO-1/GPO 14 RVS 15 DVDD 16 AVDD

Id: 2/35 Title: Power Supply Sink


3 REFIO 4 REFGND 5 REFCAP 6 AIN_P 7 AIN_GND 8 ~{RST} 9GND

3 REFIO 4 REFGND 5 REFCAP 6 AIN_P 7 AIN_GND 8 ~{RST} 9 U301 ADS8665IPWR

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

Id: 3/35 Title: Power Supply Sink


Id: 4/35 Title: Power Supply Sink

diode-network File: diode-network.kicad_sch C518

Id: 5/35 Title: Power Supply Sink


Id: 6/35 Title: Power Supply Sink


File: digital-interface.kicad_sch Sheet: /digital-interface/
Id: 7/35 Title: Power Supply Sink

conf_refselect_i comp_mgtt comp_mstt mode-transition File: mode-transition.kicad_sch

JP807 +10V_limit-logic C801
conf_refselect_i compare-logic File: compare-logic.kicad_sch

File: limit-logic.kicad_sch Sheet: /limit-logic/
Id: 8/35 Title: Power Supply Sink


llul window-comparator File: window-comparator.kicad_sch

llul window-comparator1 File: window-comparator.kicad_sch

llul window-comparator2 File: window-comparator.kicad_sch

llul window-comparator3 File: window-comparator.kicad_sch

File: compare-logic.kicad_sch Sheet: /limit-logic/compare-logic/
Id: 9/35 Title: Power Supply Sink


File: window-comparator.kicad_sch Sheet: /limit-logic/compare-logic/window-comparator/
Id: 10/35 Title: Power Supply Sink


File: window-comparator.kicad_sch Sheet: /limit-logic/compare-logic/window-comparator1/
Id: 11/35 Title: Power Supply Sink

File: window-comparator.kicad_sch Sheet: /limit-logic/compare-logic/window-comparator2/
Id: 12/35 Title: Power Supply Sink


File: window-comparator.kicad_sch Sheet: /limit-logic/compare-logic/window-comparator3/
Id: 13/35 Title: Power Supply Sink


File: mode-transition.kicad_sch Sheet: /limit-logic/mode-transition/
Id: 14/35 Title: Power Supply Sink

Id: 15/35 Title: Power Supply Sink


Id: 16/35 Title: Power Supply Sink


File: power.kicad_sch Sheet: /power/
Id: 17/35 Title: Power Supply Sink

File: power-electronics.kicad_sch Sheet: /power-electronics/
Id: 18/35 Title: Power Supply Sink


File: bias.kicad_sch Sheet: /power-electronics/bias/
Id: 19/35 Title: Power Supply Sink


File: outstage.kicad_sch Sheet: /power-electronics/outstage/
Id: 20/35 Title: Power Supply Sink

File: outstage-unit.kicad_sch Sheet: /power-electronics/outstage/outstage-unit/
Id: 21/35 Title: Power Supply Sink


File: emitter_follower.kicad_sch Sheet: /power-electronics/outstage/outstage-unit/emitter_follower1/
Id: 22/35 Title: Power Supply Sink


File: emitter_follower.kicad_sch Sheet: /power-electronics/outstage/outstage-unit/emitter_follower2/
Id: 23/35 Title: Power Supply Sink

File: emitter_follower.kicad_sch Sheet: /power-electronics/outstage/outstage-unit/emitter_follower3/
Id: 24/35 Title: Power Supply Sink


File: emitter_follower.kicad_sch Sheet: /power-electronics/outstage/outstage-unit/emitter_follower4/
Id: 25/35 Title: Power Supply Sink


File: emitter_follower.kicad_sch Sheet: /power-electronics/outstage/outstage-unit/emitter_follower5/
Id: 26/35 Title: Power Supply Sink


File: emitter_follower.kicad_sch Sheet: /power-electronics/outstage/outstage-unit/emitter_follower6/
Id: 27/35 Title: Power Supply Sink

File: outstage-unit.kicad_sch Sheet: /power-electronics/outstage/outstage-unit1/
Id: 28/35 Title: Power Supply Sink


File: emitter_follower.kicad_sch Sheet: /power-electronics/outstage/outstage-unit1/emitter_follower1/
Id: 29/35 Title: Power Supply Sink

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

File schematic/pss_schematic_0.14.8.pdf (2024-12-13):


SCKL SDI digital-interface File: digital-interface.kicad_sch
~{CS_ISO} SDI_ISO
SCKL_ISO

adc1 File: adc.kicad_sch AIN_P SDI CONVST/~{CS} SCKL SDO-0

ref control-var File: control-var.kicad_sch

v_in v_out power-electronics File: power-electronics.kicad_sch

limit-logic File: limit-logic.kicad_sch
conf_ok power_ok

Id: 1/35 Title: Power Supply Sink

3 REFIO 4 REFGND 5 REFCAP 6 AIN_P 7 AIN_GND 8 ~{RST} 9 U201 ADS8665IPWR GND

1 SDI 10 CONVST/~{CS} 11 SCKL 12 SDO-0 13 ALARM/SDO-1/GPO 14 RVS 15 DVDD 16 AVDD

3 REFIO 4 REFGND 5 REFCAP 6 AIN_P 7 AIN_GND 8 ~{RST} 9 GND

Id: 2/35 Title: Power Supply Sink


3 REFIO 4 REFGND 5 REFCAP 6 AIN_P 7 AIN_GND 8 ~{RST} 9 U301 ADS8665IPWR

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

3 REFIO 4 REFGND 5 REFCAP 6 AIN_P 7 AIN_GND 8 ~{RST} 9 GND

Id: 3/35 Title: Power Supply Sink


Id: 4/35 Title: Power Supply Sink

diode-network File: diode-network.kicad_sch R510

Id: 5/35 Title: Power Supply Sink


Id: 6/35 Title: Power Supply Sink


File: digital-interface.kicad_sch Sheet: /digital-interface/
Id: 7/35 Title: Power Supply Sink

conf_refselect_i comp_mgtt comp_mstt mode-transition File: mode-transition.kicad_sch

conf_refselect_i compare-logic File: compare-logic.kicad_sch

File: limit-logic.kicad_sch Sheet: /limit-logic/
Id: 8/35 Title: Power Supply Sink


llul window-comparator File: window-comparator.kicad_sch

llul window-comparator1 File: window-comparator.kicad_sch

llul window-comparator2 File: window-comparator.kicad_sch

llul window-comparator3 File: window-comparator.kicad_sch

File: compare-logic.kicad_sch Sheet: /limit-logic/compare-logic/
Id: 9/35 Title: Power Supply Sink


File: window-comparator.kicad_sch Sheet: /limit-logic/compare-logic/window-comparator/
Id: 10/35 Title: Power Supply Sink


File: window-comparator.kicad_sch Sheet: /limit-logic/compare-logic/window-comparator1/
Id: 11/35 Title: Power Supply Sink

File: window-comparator.kicad_sch Sheet: /limit-logic/compare-logic/window-comparator2/
Id: 12/35 Title: Power Supply Sink


File: window-comparator.kicad_sch Sheet: /limit-logic/compare-logic/window-comparator3/
Id: 13/35 Title: Power Supply Sink


File: mode-transition.kicad_sch Sheet: /limit-logic/mode-transition/
Id: 14/35 Title: Power Supply Sink

Id: 15/35 Title: Power Supply Sink


Id: 16/35 Title: Power Supply Sink


File: power.kicad_sch Sheet: /power/
Id: 17/35 Title: Power Supply Sink

File: power-electronics.kicad_sch Sheet: /power-electronics/
Id: 18/35 Title: Power Supply Sink


File: bias.kicad_sch Sheet: /power-electronics/bias/
Id: 19/35 Title: Power Supply Sink


File: outstage.kicad_sch Sheet: /power-electronics/outstage/
Id: 20/35 Title: Power Supply Sink

File: outstage-unit.kicad_sch Sheet: /power-electronics/outstage/outstage-unit/
Id: 21/35 Title: Power Supply Sink


File: emitter_follower.kicad_sch Sheet: /power-electronics/outstage/outstage-unit/emitter_follower1/
Id: 22/35 Title: Power Supply Sink


File: emitter_follower.kicad_sch Sheet: /power-electronics/outstage/outstage-unit/emitter_follower2/
Id: 23/35 Title: Power Supply Sink

File: emitter_follower.kicad_sch Sheet: /power-electronics/outstage/outstage-unit/emitter_follower3/
Id: 24/35 Title: Power Supply Sink


File: emitter_follower.kicad_sch Sheet: /power-electronics/outstage/outstage-unit/emitter_follower4/
Id: 25/35 Title: Power Supply Sink


File: emitter_follower.kicad_sch Sheet: /power-electronics/outstage/outstage-unit/emitter_follower5/
Id: 26/35 Title: Power Supply Sink


File: emitter_follower.kicad_sch Sheet: /power-electronics/outstage/outstage-unit/emitter_follower6/
Id: 27/35 Title: Power Supply Sink

File: outstage-unit.kicad_sch Sheet: /power-electronics/outstage/outstage-unit1/
Id: 28/35 Title: Power Supply Sink


File: emitter_follower.kicad_sch Sheet: /power-electronics/outstage/outstage-unit1/emitter_follower1/
Id: 29/35 Title: Power Supply Sink

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

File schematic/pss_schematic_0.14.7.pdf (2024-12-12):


SCKL SDI digital-interface File: digital-interface.kicad_sch
~{CS_ISO} SDI_ISO
SCKL_ISO

adc1 File: adc.kicad_sch AIN_P SDI CONVST/~{CS} SCKL SDO-0

ref control-var File: control-var.kicad_sch

v_in v_out power-electronics File: power-electronics.kicad_sch

limit-logic File: limit-logic.kicad_sch
conf_ok power_ok

Id: 1/35 Title: Power Supply Sink

3 REFIO 4 REFGND 5 REFCAP 6 AIN_P 7 AIN_GND 8 ~{RST} 9 GND

3 REFIO 4 REFGND 5 REFCAP 6 AIN_P 7 AIN_GND 8 ~{RST} 9 U201 ADS8665IPWR R203

1 SDI 10 CONVST/~{CS} 11 SCKL 12 SDO-0 13 ALARM/SDO-1/GPO 14 RVS 15 DVDD 16 AVDD
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

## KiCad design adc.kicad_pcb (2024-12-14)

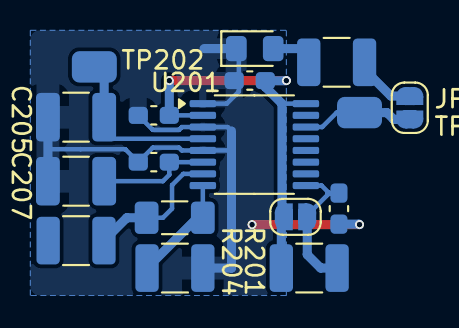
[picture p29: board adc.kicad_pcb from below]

Board: 2 copper layers, 17 parts (17 on the bottom side), 10 nets.

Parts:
C201, C202, C203, C206: 1u; C_0603_1608Metric_Pad1.08x0.95mm_HandSolder
C204: 47n; C_1206_3216Metric_Pad1.33x1.80mm_HandSolder
C205, C207: 10u; C_1210_3225Metric_Pad1.33x2.70mm_HandSolder
D201: LED; LED_0805_2012Metric_Pad1.15x1.40mm_HandSolder
JP201: SolderJumper_2_Open; SolderJumper-2_P1.3mm_Open_RoundedPad1.0x1.5mm
JP202: SolderJumper_2_Bridged; SolderJumper-2_P1.3mm_Bridged-Soldermask-Paste_RoundedPad1.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
R201: 1k; R_1210_3225Metric_Pad1.30x2.65mm_HandSolder
R202: 10k; R_1210_3225Metric_Pad1.30x2.65mm_HandSolder
R203, R204: 100; R_1210_3225Metric_Pad1.30x2.65mm_HandSolder
TP201, TP202: TP_0805_2012Metric
U201: ADS8665IPWR; TSSOP-16_4.4x5mm_P0.65mm

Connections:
+5VA_adc: C202.2, C203.2, JP201.1 (A), R201.1, U201.2 (AVDD), U201.16 (DVDD)
/AIN_GND: C204.1, R204.1, U201.8 (AIN_GND)
/AIN_P_int: C204.2, R203.1, U201.7 (AIN_P)
/GPO: JP202.2 (B), TP201.1, U201.14 (ALARM/SDO-1/GPO)
/GPO_JMP: JP202.1 (A), R202.1
/GPO_LED: D201.2 (A), R202.2
/REFCAP: C206.2, C207.2, U201.6 (REFCAP)
/REFIO: C205.2, TP202.1, U201.4 (REFIO)
/~RST: C201.2, JP201.2 (B), R201.2, U201.9 (~RST)
GND: C201.1, C202.1, C203.1, C205.1, C206.1, C207.1, D201.1 (K), R204.2, U201.1 (DGND), U201.3 (AGND), U201.5 (REFGND)

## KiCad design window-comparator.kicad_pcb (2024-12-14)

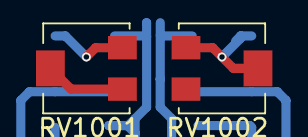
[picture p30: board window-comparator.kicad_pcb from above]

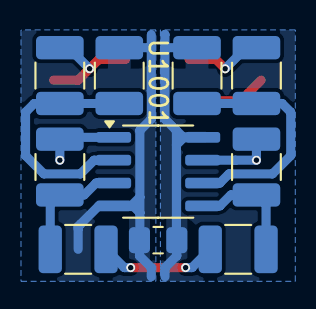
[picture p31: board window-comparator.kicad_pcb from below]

Board: 2 copper layers, 12 parts (10 on the bottom side), 12 nets.

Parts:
C1001: 100n; C_0805_2012Metric_Pad1.18x1.45mm_HandSolder
R1001, R1004: 100k; R_1210_3225Metric_Pad1.30x2.65mm_HandSolder
R1002, R1003: 22; R_1210_3225Metric_Pad1.30x2.65mm_HandSolder
R1005, R1006: 0; R_1210_3225Metric_Pad1.30x2.65mm_HandSolder
R1007, R1008: 1M; R_1210_3225Metric_Pad1.30x2.65mm_HandSolder
RV1001, RV1002: 1k; Potentiometer_Bourns_PVG5H
U1001: TLV9352; SOIC-8_3.9x4.9mm_P1.27mm

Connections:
+10V_compare-logic: C1001.2, R1001.1, U1001.8 (V+)
-5V_compare-logic: C1001.1, R1004.2, U1001.4 (V-)
/l+: R1006.2, R1008.1, U1001.3 (+)
/l-: R1003.2, R1004.1, U1001.2 (-)
/lpot: R1003.1, RV1002.2, RV1002.3
/meas: R1005.1, R1006.1
/u+: R1005.2, R1007.1, U1001.5 (+)
/u-: R1001.2, R1002.1, U1001.6 (-)
/ul: RV1001.2, RV1001.3
/ule: R1007.2, U1001.7
/upot: R1002.2, RV1001.1
/~lle: R1008.2, U1001.1

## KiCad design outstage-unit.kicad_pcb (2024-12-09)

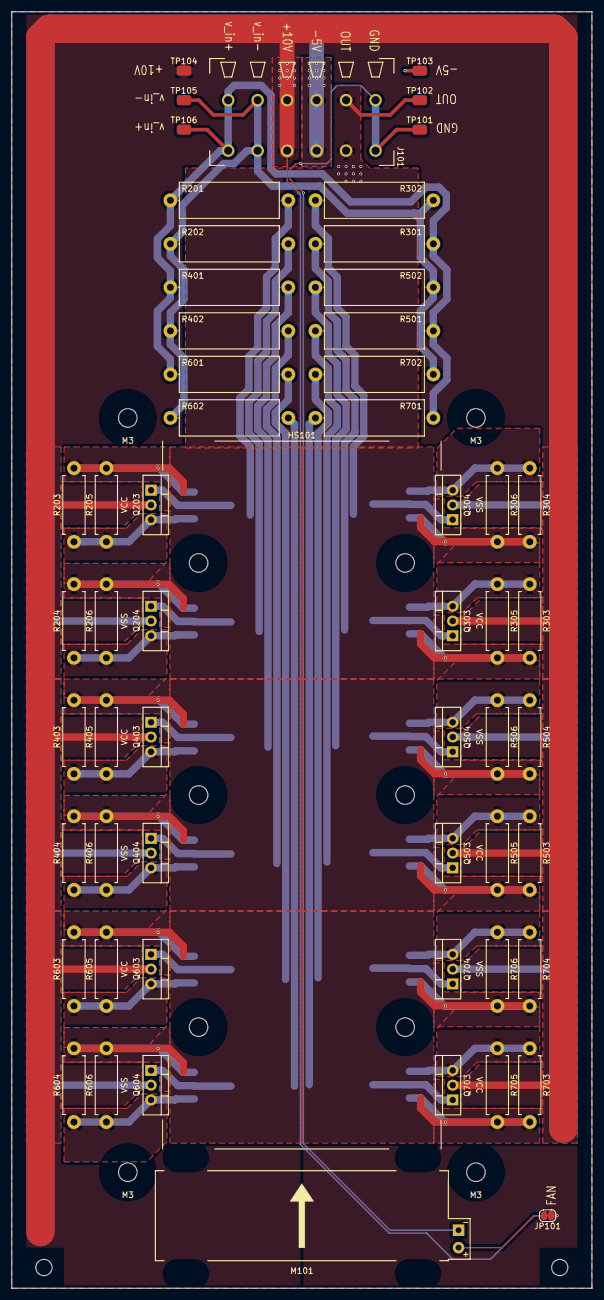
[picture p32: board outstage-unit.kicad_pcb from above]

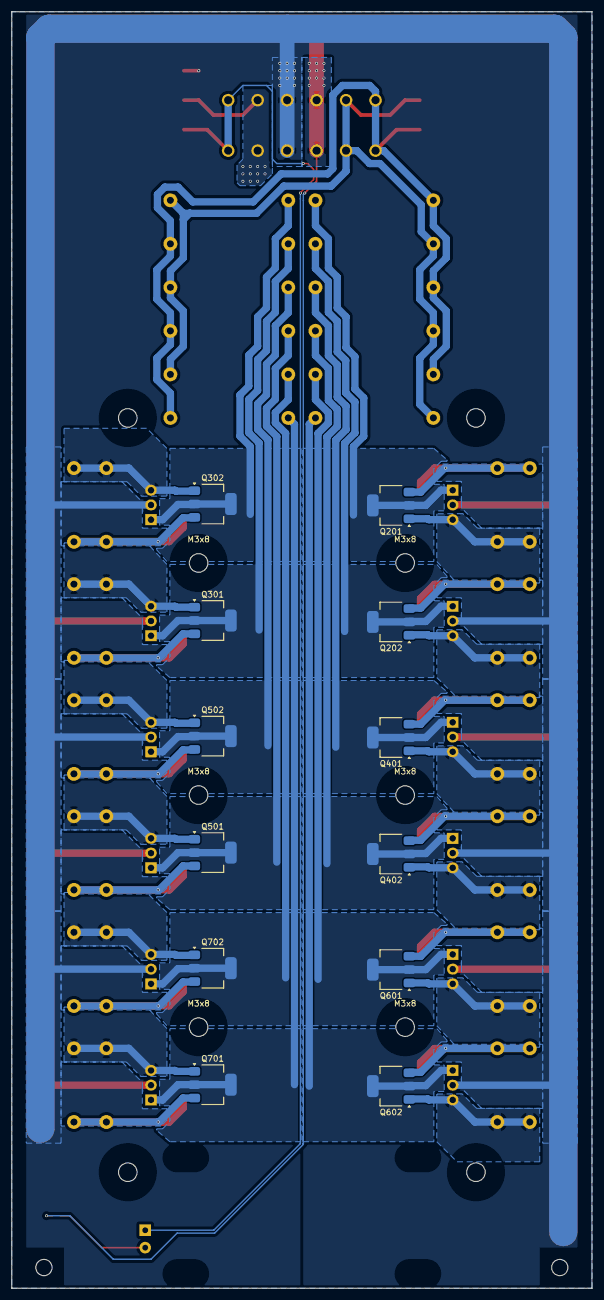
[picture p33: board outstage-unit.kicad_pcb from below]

Board: 2 copper layers, 100.0 x 220.0 mm, 70 parts (12 on the bottom side), 31 nets.

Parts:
HS101: SK499-120 SA; Heatsink_Fischer_SK499-120_46x120mm_h33mm_Drill3.5mm_ScrewM3
J101: Conn_01x06_Socket; PhoenixContact_TDPT_2,5_6-SP-5,08_1x06_P5.08mm_Horizontal
JP101: SolderJumper_2_Bridged; SolderJumper-2_P1.3mm_Bridged-Soldermask-Paste_RoundedPad1.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
M101: Fan; Fan_SameSky_CFM-5015V
Q201, Q301, Q401, Q501, Q601, Q701: DNLS350E; SOT-223-3_TabPin2
Q202, Q302, Q402, Q502, Q602, Q702: DPLS350E; SOT-223-3_TabPin2
Q203, Q303, Q403, Q503, Q603, Q703: TIP41C; TO-220-3_Vertical
Q204, Q304, Q404, Q504, Q604, Q704: TIP42C; TO-220-3_Vertical
R201, R202, R301, R302, R401, R402, R501, R502, R601, R602, R701, R702: 22; R_Axial_DIN0617_L17.0mm_D6.0mm_P20.32mm_Horizontal
R203, R204, R205, R206, R303, R304, R305, R306, R403, R404, R405, R406, R503, R504, R505, R506, R603, R604, R605, R606, R703, R704, R705, R706: 680m; R_Axial_DIN0411_L9.9mm_D3.6mm_P12.70mm_Horizontal
TP101, TP102, TP103, TP104, TP105, TP106: TP_0805_2012Metric

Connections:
/+10V: J101.4, JP101.1 (A), Q203.2 (C), Q303.2 (C), Q403.2 (C), Q503.2 (C), Q603.2 (C), Q703.2 (C), TP104.1
/-5V: J101.3, Q204.2 (C), Q304.2 (C), Q404.2 (C), Q504.2 (C), Q604.2 (C), Q704.2 (C), TP103.1
/GND: J101.1, M101.2 (-), TP101.1
/v_in+: J101.6, R201.1, R301.1, R401.1, R501.1, R601.1, R701.1, TP106.1
/v_in-: J101.5, R202.1, R302.1, R402.1, R502.1, R602.1, R702.1, TP105.1
/v_out: J101.2, Q201.3 (E), Q202.3 (E), Q301.3 (E), Q302.3 (E), Q401.3 (E), Q402.3 (E), Q501.3 (E), Q502.3 (E), Q601.3 (E), Q602.3 (E), Q701.3 (E), Q702.3 (E), R203.2, R204.1, R205.2, R206.1, R303.2, R304.1, R305.2, R306.1, R403.2, R404.1, R405.2, R406.1, R503.2, R504.1, R505.2, R506.1, R603.2, R604.1, R605.2, R606.1, R703.2, R704.1, R705.2, R706.1, TP102.1
unnamed: JP101.2 (B), M101.1 (+)
unnamed: Q201.1 (B), Q203.3 (E), R203.1, R205.1
unnamed: Q201.2 (C), Q203.1 (B), R201.2
unnamed: Q202.1 (B), Q204.3 (E), R204.2, R206.2
unnamed: Q202.2 (C), Q204.1 (B), R202.2
unnamed: Q301.1 (B), Q303.3 (E), R303.1, R305.1
unnamed: Q301.2 (C), Q303.1 (B), R301.2
unnamed: Q302.1 (B), Q304.3 (E), R304.2, R306.2
unnamed: Q302.2 (C), Q304.1 (B), R302.2
unnamed: Q401.1 (B), Q403.3 (E), R403.1, R405.1
unnamed: Q401.2 (C), Q403.1 (B), R401.2
unnamed: Q402.1 (B), Q404.3 (E), R404.2, R406.2
unnamed: Q402.2 (C), Q404.1 (B), R402.2
unnamed: Q501.1 (B), Q503.3 (E), R503.1, R505.1
unnamed: Q501.2 (C), Q503.1 (B), R501.2
unnamed: Q502.1 (B), Q504.3 (E), R504.2, R506.2
unnamed: Q502.2 (C), Q504.1 (B), R502.2
unnamed: Q601.1 (B), Q603.3 (E), R603.1, R605.1
unnamed: Q601.2 (C), Q603.1 (B), R601.2
unnamed: Q602.1 (B), Q604.3 (E), R604.2, R606.2
unnamed: Q602.2 (C), Q604.1 (B), R602.2
unnamed: Q701.1 (B), Q703.3 (E), R703.1, R705.1
unnamed: Q701.2 (C), Q703.1 (B), R701.2
unnamed: Q702.1 (B), Q704.3 (E), R704.2, R706.2
unnamed: Q702.2 (C), Q704.1 (B), R702.2

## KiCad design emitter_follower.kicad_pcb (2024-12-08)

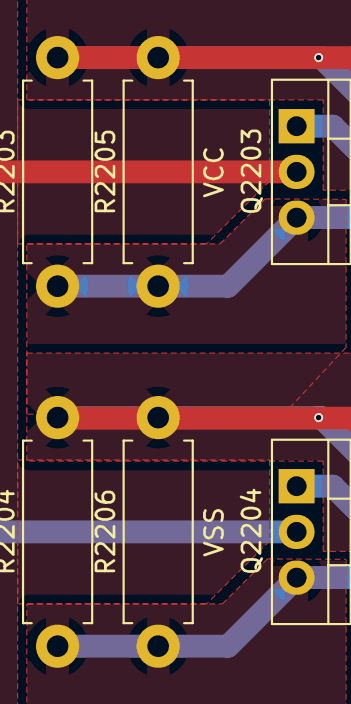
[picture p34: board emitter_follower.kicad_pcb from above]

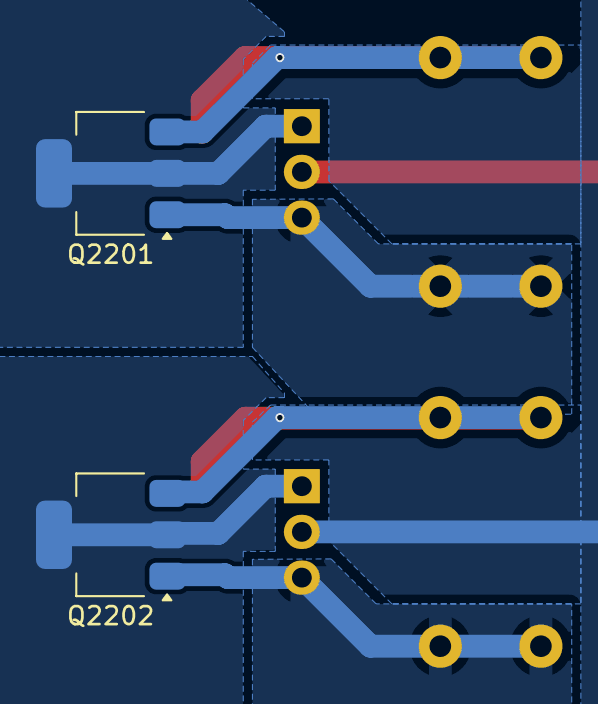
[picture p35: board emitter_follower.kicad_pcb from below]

Board: 2 copper layers, 8 parts (2 on the bottom side), 5 nets.

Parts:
Q2201: DNLS350E; SOT-223-3_TabPin2
Q2202: DPLS350E; SOT-223-3_TabPin2
Q2203: TIP41C; TO-220-3_Vertical
Q2204: TIP42C; TO-220-3_Vertical
R2203, R2204, R2205, R2206: 680m; R_Axial_DIN0411_L9.9mm_D3.6mm_P12.70mm_Horizontal

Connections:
/1: Q2201.1 (B), Q2203.3 (E), R2203.1, R2205.1
/2: Q2202.1 (B), Q2204.3 (E), R2204.2, R2206.2
/3: Q2201.2 (C), Q2203.1 (B)
/4: Q2202.2 (C), Q2204.1 (B)
/v_out: Q2201.3 (E), Q2202.3 (E), R2203.2, R2204.1, R2205.2, R2206.1

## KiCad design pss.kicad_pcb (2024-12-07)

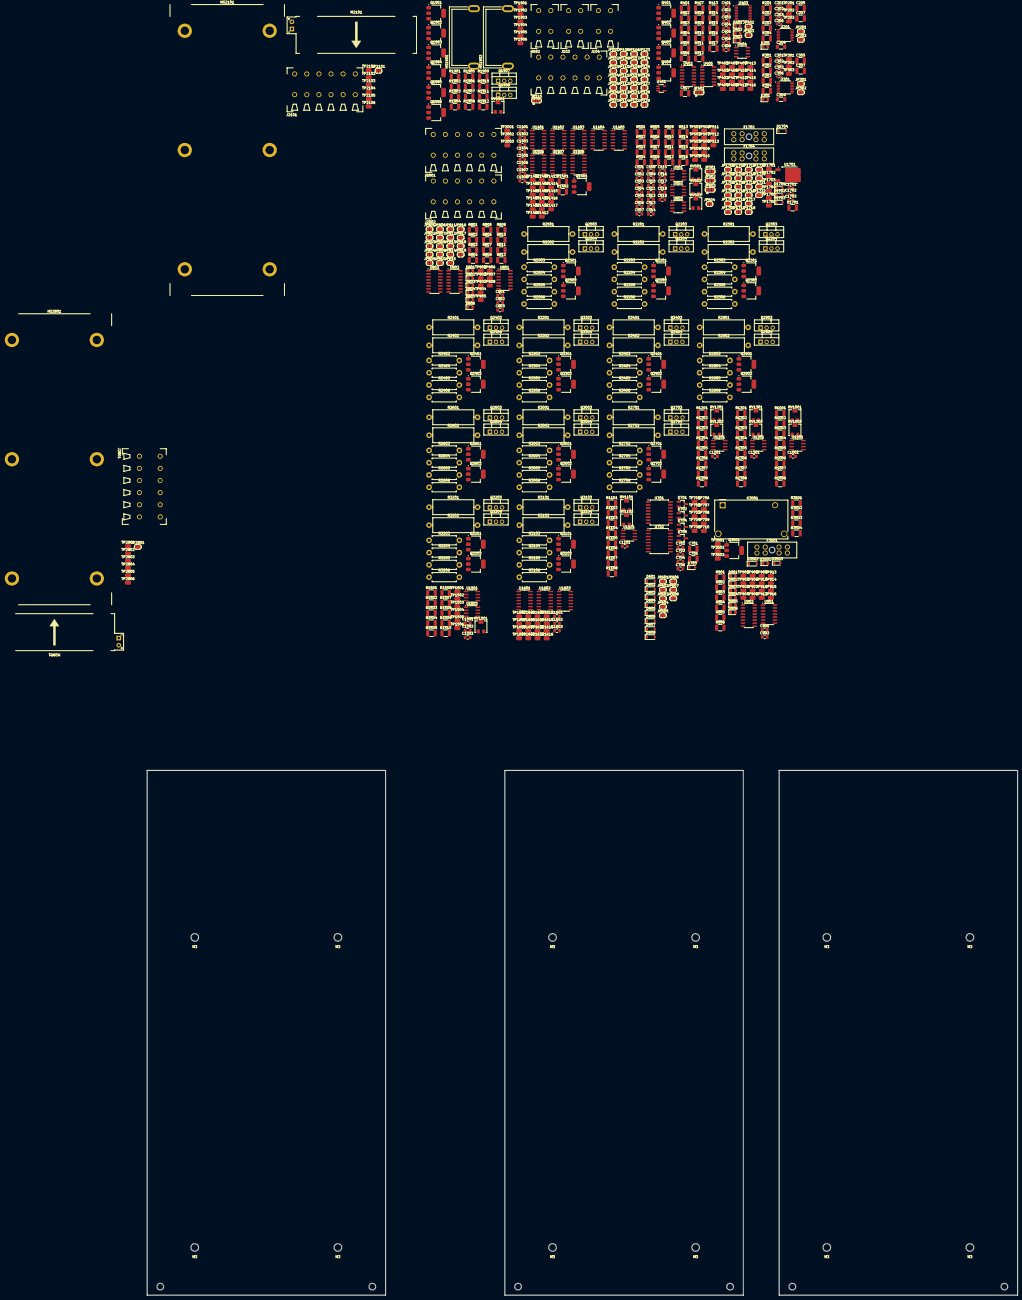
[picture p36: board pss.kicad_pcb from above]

Board: 2 copper layers, 365.0 x 220.0 mm, 659 parts (0 on the bottom side), 350 nets, no tracks yet.

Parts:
C201, C202, C203, C206, C301, C302, C303, C306, C1701, C1702, C1703: 1u; C_0603_1608Metric_Pad1.08x0.95mm_HandSolder
C204, C304: 47n; C_1206_3216Metric_Pad1.33x1.80mm_HandSolder
C205, C207, C305, C307, C407, C701, C705: 10u; C_1210_3225Metric_Pad1.33x2.70mm_HandSolder
C401, C402, C403, C404, C405, C406, C408, C702, C703, C704, C706, C801, C802, C803, C901, C902, C1001, C1101, C1201, C1301, C1401, C1402, C1403, C1404, C1405, C1406, C1407, C1408, C1501, C1502, C1601, C1602, C1603: 100n; C_0805_2012Metric_Pad1.18x1.45mm_HandSolder
C501, C502, C503, C508, C509, C512, C513, C514, C519: 10n; C_0805_2012Metric_Pad1.18x1.45mm_HandSolder
C504, C505, C510, C511, C515, C516: 2u2; C_0805_2012Metric_Pad1.18x1.45mm_HandSolder
C506, C507, C517, C518, C1503: 1n; C_0805_2012Metric_Pad1.18x1.45mm_HandSolder
D201, D301, D401, D402, D403, D801, D802, D803, D804, D805, D806, D901, D902, D903, D904, D905, D906, D3501: LED; LED_0805_2012Metric_Pad1.15x1.40mm_HandSolder
D601, D602, D603, D604, D605, D606, D607, D608, D1704, D3502: 1N4148; D_SOD-123
D701, D702, D704, D705: NUP1301215; SOT-23_Handsoldering
D703: PDZ5.6B115; D_SOD-323_HandSoldering
D1701, D1702, D1703, D3503: D_TVS; D_SOD-323_HandSoldering
F1702, F1704, F3501: Fuse_Socket; FuseHolder_Blade_ATO_Littelfuse_FLR_178.6165
HS1901, HS1902: TO220-FIN; Heatsink_AAVID_575002B00000G
HS2101, HS2801: SK499-120 SA; Heatsink_Fischer_SK499-120_46x120mm_h33mm_Drill3.5mm_ScrewM3
J101, J2001, J2002, J2101, J2801: Conn_01x06_Socket; PhoenixContact_TDPT_2,5_6-SP-5,08_1x06_P5.08mm_Horizontal
J102, J103, J104: Conn_01x02_Socket; PhoenixContact_TDPT_2,5_2-SP-5,08_1x02_P5.08mm_Horizontal
JP101, JP102, JP103, JP104, JP105, JP106, JP107, JP108, JP109, JP110, JP111, JP112, JP113, JP116, JP117, JP118, JP119, JP120, JP121, JP122, JP123, JP124, JP125, JP126, JP127, JP128, JP129, JP201, JP301, JP402, JP403, JP504, JP601, JP602, JP603, JP605, JP801, JP802, JP803, JP804, JP805, JP806, JP807, JP808, JP809, JP810, JP811, JP812, JP813, JP814, JP815, JP816, JP817, JP818, JP819, JP1701, JP1702, JP1703, JP1704, JP1705, JP1706, JP1707, JP1708, JP1709, JP1710, JP1711, JP1712, JP1713, JP1714, JP1715, JP1716, JP1717, JP1718, JP1719, JP1720, JP1721, JP1722: SolderJumper_2_Open; SolderJumper-2_P1.3mm_Open_RoundedPad1.0x1.5mm
JP114, JP202, JP302, JP604, JP606, JP607, JP608, JP2101, JP2801: SolderJumper_2_Bridged; SolderJumper-2_P1.3mm_Bridged-Soldermask-Paste_RoundedPad1.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
JP115, JP401, JP501, JP502, JP503: SolderJumper_3_Bridged12; SolderJumper-3_P1.3mm_Bridged12-Soldermask-Paste_RoundedPad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
K3501: ALFG2PF12; Relay_SPST_Panasonic_ALFG_FormA_CircularHoles
M2101, M2801: Fan; Fan_SameSky_CFM-5015V
Q401, Q402, Q1401, Q1902, Q1905, Q1906, Q2201, Q2301, Q2401, Q2501, Q2601, Q2701, Q2901, Q3001, Q3101, Q3201, Q3301, Q3401: DNLS350E; SOT-223-3_TabPin2
Q403, Q404, Q1901, Q1903, Q1904, Q2202, Q2302, Q2402, Q2502, Q2602, Q2702, Q2902, Q3002, Q3102, Q3202, Q3302, Q3402, Q3501: DPLS350E; SOT-223-3_TabPin2
Q1907, Q2203, Q2303, Q2403, Q2503, Q2603, Q2703, Q2903, Q3003, Q3103, Q3203, Q3303, Q3403: TIP41C; TO-220-3_Vertical
Q1908, Q2204, Q2304, Q2404, Q2504, Q2604, Q2704, Q2904, Q3004, Q3104, Q3204, Q3304, Q3404: TIP42C; TO-220-3_Vertical
R201, R301, R1701, R1910: 1k; R_1210_3225Metric_Pad1.30x2.65mm_HandSolder
R202, R302, R403, R406, R408, R409, R410, R503, R504, R505, R506, R507, R508, R511, R512, R513, R807, R808, R809, R810, R811, R812, R901, R902, R903, R904, R905, R906, R1503, R1504, R1505, R1506, R1507, R1508, R1509, R1510, R3501, R3503: 10k; R_1210_3225Metric_Pad1.30x2.65mm_HandSolder
R203, R204, R303, R304, R1903: 100; R_1210_3225Metric_Pad1.30x2.65mm_HandSolder
R401, R402, R411, R412, R413, R417, R501, R502, R1007, R1008, R1107, R1108, R1207, R1208, R1307, R1308, R1401, R3502: 1M; R_1210_3225Metric_Pad1.30x2.65mm_HandSolder
R404, R405, R801, R802, R803, R804, R805, R806, R1001, R1004, R1101, R1104, R1201, R1204, R1301, R1304: 100k; R_1210_3225Metric_Pad1.30x2.65mm_HandSolder
R407, R416, R1005, R1006, R1105, R1106, R1205, R1206, R1305, R1306: 0; R_1210_3225Metric_Pad1.30x2.65mm_HandSolder
R414, R415, R1402: 15k; R_1210_3225Metric_Pad1.30x2.65mm_HandSolder
R509: 1k6; R_1210_3225Metric_Pad1.30x2.65mm_HandSolder
R510, R1902, R1908, R1909: 8k2; R_1210_3225Metric_Pad1.30x2.65mm_HandSolder
R514: 330; R_1210_3225Metric_Pad1.30x2.65mm_HandSolder
R515: 4k7; R_1210_3225Metric_Pad1.30x2.65mm_HandSolder
R516: 33k; R_1210_3225Metric_Pad1.30x2.65mm_HandSolder
R1002, R1003, R1102, R1103, R1202, R1203, R1302, R1303, R3504: 22; R_1210_3225Metric_Pad1.30x2.65mm_HandSolder
R1501: 5k76; R_1210_3225Metric_Pad1.30x2.65mm_HandSolder
R1502: 9k1; R_1210_3225Metric_Pad1.30x2.65mm_HandSolder
R1901, R1907: 1k2; R_1210_3225Metric_Pad1.30x2.65mm_HandSolder
R1904: 68; R_1210_3225Metric_Pad1.30x2.65mm_HandSolder
R1905, R1911, R1912: 33; R_1210_3225Metric_Pad1.30x2.65mm_HandSolder
R1906: 270; R_1210_3225Metric_Pad1.30x2.65mm_HandSolder
R2201, R2202, R2301, R2302, R2401, R2402, R2501, R2502, R2601, R2602, R2701, R2702, R2901, R2902, R3001, R3002, R3101, R3102, R3201, R3202, R3301, R3302, R3401, R3402: 22; R_Axial_DIN0617_L17.0mm_D6.0mm_P20.32mm_Horizontal
R2203, R2204, R2205, R2206, R2303, R2304, R2305, R2306, R2403, R2404, R2405, R2406, R2503, R2504, R2505, R2506, R2603, R2604, R2605, R2606, R2703, R2704, R2705, R2706, R2903, R2904, R2905, R2906, R3003, R3004, R3005, R3006, R3103, R3104, R3105, R3106, R3203, R3204, R3205, R3206, R3303, R3304, R3305, R3306, R3403, R3404, R3405, R3406: 680m; R_Axial_DIN0411_L9.9mm_D3.6mm_P12.70mm_Horizontal
RV501, RV502: 10k; Potentiometer_Bourns_PVG5H
RV503: 100k; Potentiometer_Bourns_PVG5H
RV1001, RV1002, RV1101, RV1102, RV1201, RV1202, RV1301, RV1302, RV1501, RV1901: 1k; Potentiometer_Bourns_PVG5H
TP201, TP202, TP203, TP301, TP302, TP303, TP401, TP402, TP403, TP404, TP405, TP406, TP407, TP408, TP409, TP410, TP411, TP412, TP413, TP414, TP415, TP416, TP501, TP502, TP503, TP504, TP505, TP506, TP507, TP508, TP509, TP510, TP511, TP512, TP513, TP701, TP702, TP703, TP704, TP705, TP706, TP707, TP708, TP709, TP710, TP801, TP802, TP803, TP804, TP805, TP806, TP807, TP808, TP901, TP902, TP903, TP904, TP905, TP906, TP907, TP908, TP909, TP910, TP911, TP912, TP913, TP914, TP915, TP916, TP1401, TP1402, TP1403, TP1404, TP1405, TP1406, TP1407, TP1408, TP1409, TP1410, TP1411, TP1412, TP1413, TP1414, TP1415, TP1416, TP1417, TP1501, TP1502, TP1503, TP1504, TP1505, TP1506, TP1601, TP1602, TP1603, TP1604, TP1605, TP1606, TP1607, TP1608, TP1609, TP1610, TP1611, TP1612, TP1613, TP1614, TP1615, TP1616, TP1701, TP1702, TP1703, TP1704, TP1705, TP1706, TP1901, TP1902, TP1903, TP1904, TP1905, TP1906, TP2001, TP2002, TP2003, TP2101, TP2102, TP2103, TP2104, TP2105, TP2106, TP2801, TP2802, TP2803, TP2804, TP2805, TP2806, TP3501, TP3502, TP3503: TP_0805_2012Metric
U201, U301: ADS8665IPWR; TSSOP-16_4.4x5mm_P0.65mm
U401: SN74LVC1G04DBVR; SOT-23-5_HandSoldering
U402: 4085; SOIC-14_3.9x8.7mm_P1.27mm
U403: AD567xR; TSSOP-20_4.4x6.5mm_P0.65mm
U404, U1001, U1101, U1201, U1301, U1501: TLV9352; SOIC-8_3.9x4.9mm_P1.27mm
U405: 4041; SOIC-14_3.9x8.7mm_P1.27mm
U501, U502, U503: OPA2810; SOIC-8_3.9x4.9mm_P1.27mm
U701: Si8641BD-B-IS2; SOIC-16W_7.5x10.3mm_P1.27mm
U702: R05C05TE05S; SOIC-16W_7.5x10.3mm_P1.27mm
U801: 4078; SOIC-14_3.9x8.7mm_P1.27mm
U802, U803: 4043; SOIC-16_3.9x9.9mm_P1.27mm
U901, U1404: 4069; SOIC-14_3.9x8.7mm_P1.27mm
U902: 4019; SOIC-16_3.9x9.9mm_P1.27mm
U1401, U1405: 4081; SOIC-14_3.9x8.7mm_P1.27mm
U1402, U1403: 4073; SOIC-14_3.9x8.7mm_P1.27mm
U1406: 4071; SOIC-14_3.9x8.7mm_P1.27mm
U1407, U1408, U1603: 4075; SOIC-14_3.9x8.7mm_P1.27mm
U1502: ACS730xLCTR-20AB; SOIC-8_3.9x4.9mm_P1.27mm
U1601, U1602: 4066; SOIC-14_3.9x8.7mm_P1.27mm
U1701: MC7805; TO-252-2

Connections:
+5VA: C1702.2, D1704.2 (A), JP1710.1 (A), JP1711.1 (A), JP1712.1 (A), JP1713.1 (A), TP1706.1, U1701.3 (OUT)
+5VA_adc: C202.2, C203.2, C302.2, C303.2, JP201.1 (A), JP301.1 (A), JP1710.2 (B), R201.1, R301.1, U201.2 (AVDD), U201.16 (DVDD), U301.2 (AVDD), U301.16 (DVDD)
+5VA_conf: C401.2, C403.2, C405.2, C407.2, JP401.1 (A), JP1712.2 (B), U401.5 (VCC), U403.3 (VDD), U403.4 (VLOGIC), U403.8 (GAIN), U403.17 (~RESET)
+5VA_digital-interface: C704.2, C705.2, C706.2, JP1713.2 (B), U701.10 (EN2), U701.16 (VDD2), U702.3 (+VIN), U702.4 (+VIN)
+5VA_meas: C1502.2, JP1711.2 (B), R1501.1, U1502.8 (VCC)
+5VI: C701.2, C702.2, C703.2, D701.2 (K), D702.2 (K), D703.1 (K), D704.2 (K), D705.2 (K), TP705.1, U701.1 (VDD1), U701.7 (EN1), U702.13 (+VOUT), U702.14 (+VOUT)
+10V: C1701.2, D1701.2 (A2), D1703.2 (A2), D1704.1 (K), F1702.1, F1702.2, J102.2, J2001.5, J2002.5, JP1701.1 (A), JP1702.1 (A), JP1703.1 (A), JP1704.1 (A), JP1705.1 (A), JP1706.1 (A), JP1707.1 (A), JP1708.1 (A), JP1709.1 (A), R1701.2, TP1702.1, TP1704.1, U1701.1 (IN)
+10V_bias: HS1901.1, JP1701.2 (B), Q1905.2 (C), Q1907.2 (C), R1901.1, R1905.1, R1907.1, R1909.1, R1911.1
+10V_compare-logic: C901.2, C902.2, C1001.2, C1101.2, C1201.2, C1301.2, JP1702.2 (B), R1001.1, R1101.1, R1201.1, R1301.1, U901.11, U901.13, U901.14 (Vdd), U902.1 (B3), U902.15 (A3), U902.16 (Vdd), U1001.8 (V+), U1101.8 (V+), U1201.8 (V+), U1301.8 (V+)
+10V_conf: C402.2, C404.2, C408.2, JP1709.2 (B), Q403.3 (E), Q404.3 (E), R408.2, R409.2, U402.14 (VDD), U404.8 (V+), U405.13, U405.14 (Vdd)
+10V_control: C502.1, C504.1, C508.1, C510.1, C513.1, C515.1, JP1708.2 (B), U501.8 (V+), U502.8 (V+), U503.8 (V+)
+10V_limit-logic: C801.2, C802.2, C803.2, JP1704.2 (B), U801.14 (Vdd), U802.14, U802.15, U802.16 (Vdd), U803.14, U803.15, U803.16 (Vdd)
+10V_meas: C1501.2, JP1706.2 (B), U1501.8 (V+)
+10V_mode-transition: C1401.2, C1402.2, C1403.2, C1404.2, C1405.2, C1406.2, C1407.2, C1408.2, JP1703.2 (B), R1402.1, U1401.14 (Vdd), U1402.14 (Vdd), U1403.14 (Vdd), U1404.14 (Vdd), U1405.14 (Vdd), U1406.14 (Vdd), U1407.14 (Vdd), U1408.14 (Vdd)
+10V_mux: C1601.2, C1602.2, C1603.2, JP1705.2 (B), U1601.14 (VDD), U1602.14 (VDD), U1603.11, U1603.12, U1603.13, U1603.14 (Vdd)
+10V_relay: JP1707.2 (B), Q3501.3 (E), R3502.1
-5V: C801.1, C1703.1, D1702.1 (A1), D1703.1 (A1), F1704.1, F1704.2, J103.2, J2001.6, J2002.6, JP1714.1 (A), JP1715.1 (A), JP1716.1 (A), JP1717.1 (A), JP1718.1 (A), JP1719.1 (A), JP1720.1 (A), JP1721.1 (A), JP1722.1 (A), TP1703.1, TP1705.1
-5V_bias: HS1902.1, JP1714.2 (B), Q1904.2 (C), Q1908.2 (C), R1902.2, R1906.2, R1908.2, R1910.2, R1912.2
-5V_compare-logic: C901.1, C902.1, C1001.1, C1101.1, C1201.1, C1301.1, JP1715.2 (B), R901.2, R902.2, R903.2, R904.2, R905.2, R906.2, R1004.2, R1104.2, R1204.2, R1304.2, U901.7 (Vss), U902.6 (A0), U902.7 (B0), U902.8 (Vss), U1001.4 (V-), U1101.4 (V-), U1201.4 (V-), U1301.4 (V-)
-5V_conf: C404.1, JP1722.2 (B), R403.2, R406.2, R410.2, R414.2, R415.2, U402.7 (VSS), U402.8 (C2), U402.9 (D2), U402.10 (I1), U402.11 (I2), U404.4 (V-), U405.6, U405.7 (Vss)
-5V_control: C503.1, C505.1, C509.1, C511.1, C514.1, C516.1, JP1721.2 (B), U501.4 (V-), U502.4 (V-), U503.4 (V-)
-5V_limit-logic: C802.1, C803.1, JP1717.2 (B), R801.1, R802.1, R803.1, R804.1, R805.1, R806.1, R807.2, R808.2, R809.2, R810.2, R811.2, R812.2, U801.5, U801.7 (Vss), U801.12, U802.8 (Vss), U803.8 (Vss)
-5V_meas: C1501.1, JP1719.2 (B), U1501.4 (V-)
-5V_mode-transition: C1401.1, C1402.1, C1403.1, C1404.1, C1405.1, C1406.1, C1407.1, C1408.1, JP1716.2 (B), Q1401.3 (E), U1401.7 (Vss), U1402.7 (Vss), U1403.7 (Vss), U1404.7 (Vss), U1405.7 (Vss), U1406.7 (Vss), U1407.7 (Vss), U1408.7 (Vss)
-5V_mux: C1601.1, C1602.1, C1603.1, JP1718.2 (B), U1601.7 (VSS), U1602.7 (VSS), U1603.7 (Vss)
-5V_relay: D3502.2 (A), JP1720.2 (B), K3501.A2, R3501.2
/SCKL: JP108.2 (B), U201.12 (SCKL), U301.12 (SCKL), U401.2 (A)
/SDI: JP109.2 (B), U403.7 (SDI)
/SDO: JP110.2 (B), JP114.2 (B), JP115.3 (B)
/adc1/SDO-0: JP114.1 (A), U301.13 (SDO-0)
/adc/SDI: JP115.1 (A), U201.10 (SDI)
/adc/SDO-0: U201.13 (SDO-0), U301.10 (SDI)
/conf/SDO: JP115.2 (C), U403.16 (SDO)
/conf/conf_iref: JP120.1 (A), TP406.1, U403.19 (VOUT3)
/conf/conf_lcl: JP122.1 (A), R416.1, TP409.1, U403.10 (VOUT6)
/conf/conf_lvl: JP119.1 (A), R407.1, TP407.1, U403.12 (VOUT4)
/conf/conf_ok: D401.2 (A), JP124.1 (A), TP401.1, U402.3 (E1), U402.5 (A2)
/conf/conf_output: U402.6 (B2), U405.1
/conf/conf_output_dac: JP402.1 (A), TP403.1, U403.2 (VOUT0)
/conf/conf_output_vshift: Q403.2 (C), R414.1, TP414.1, U405.3
/conf/conf_refselect_dac: JP403.1 (A), TP404.1, U403.1 (VOUT1)
/conf/conf_refselect_i: D403.2 (A), JP126.1 (A), U402.12 (C1), U405.8
/conf/conf_refselect_v: D402.2 (A), JP125.1 (A), U402.1 (A1), U405.9
/conf/conf_refselect_vshift: Q404.2 (C), R415.1, TP415.1, U405.10
/conf/conf_ucl: JP121.1 (A), TP410.1, U403.9 (VOUT7), U404.6 (-)
/conf/conf_uvl: JP118.1 (A), TP408.1, U403.11 (VOUT5), U404.2 (-)
/conf/conf_vref: JP117.1 (A), TP405.1, U403.20 (VOUT2)
/conf/~limits_ok_i: R417.2, TP416.1, U402.13 (D1), U404.7
/conf/~limits_ok_v: R411.2, TP413.1, U402.2 (B1), U404.1
/conf/~relay_connect: JP123.1 (A), TP402.1, U402.4 (E2)
/conf_iref: JP120.2 (B), RV1101.2, RV1101.3, RV1102.1, TP904.1, TP1604.1, U1602.1
/conf_lcl: JP122.2 (B), RV1302.1, TP908.1, TP1603.1, U1601.11
/conf_lvl: JP119.2 (B), RV1202.1, TP906.1, TP1606.1, U1602.11
/conf_ok: JP124.2 (B), TP1401.1, U1401.8
/conf_refselect_i: JP126.2 (B), TP914.1, U902.14 (SB), U1403.3, U1403.8, U1403.11, U1407.2, U1407.4, U1407.12
/conf_refselect_v: JP125.2 (B), TP913.1, U902.9 (SA), U1402.3, U1402.8, U1402.11, U1408.2, U1408.4, U1408.12
/conf_ucl: JP121.2 (B), RV1301.2, RV1301.3, TP907.1, TP1602.1, U1601.4
/conf_uvl: JP118.2 (B), RV1201.2, RV1201.3, TP905.1, TP1605.1, U1602.4
/conf_vref: JP117.2 (B), RV1001.2, RV1001.3, RV1002.1, TP902.1, TP1601.1, U1601.1
/control-var/derivative: C517.2, C518.2, JP503.1 (A), RV501.2, RV501.3, TP507.1, TP508.1, U502.7
/control-var/diode-network/1: D601.2 (A), D602.1 (K), JP504.2 (B), JP601.1 (A), JP602.1 (A)
/control-var/error: R505.2, R507.1, R509.2, RV503.1, TP503.1, TP511.1, U501.1
/control-var/integrator: C519.2, D607.1 (K), D608.2 (A), JP502.1 (A), JP607.2 (B), JP608.2 (B), TP513.1, U503.1
/control-var/meas: JP112.2 (B), R502.2, R504.2, TP502.1
/control-var/out: JP113.1 (A), R502.1, RV502.1, TP509.1, U501.7
/control-var/proportional: C506.2, C507.2, JP501.1 (A), R508.1, TP504.1, U502.1
/control-var/ref: JP111.2 (B), R501.1, R503.2, TP501.1
/digital-interface/SCKL: JP108.1 (A), TP708.1, U701.13 (B2)
/digital-interface/SCKL_ISO: D702.3 (K), J101.3, TP702.1, U701.4 (A2)
/digital-interface/SDI: JP109.1 (A), TP709.1, U701.12 (B3)
/digital-interface/SDI_ISO: D704.3 (K), J101.4, TP703.1, U701.5 (A3)
/digital-interface/SDO: JP110.1 (A), TP710.1, U701.11 (B4)
/digital-interface/SDO_ISO: D705.3 (K), J101.5, TP704.1, U701.6 (A4)
/digital-interface/~CS_ISO: D701.3 (K), J101.2, TP701.1, U701.3 (A1)
/digital-interface/~CS: JP107.1 (A), TP707.1, U701.14 (B1)
/limit-logic/compare-logic/comp_lcle: D905.2 (A), JP801.1 (A), TP912.1, U901.8
/limit-logic/compare-logic/comp_lvle: D903.2 (A), JP803.1 (A), TP911.1, U901.6
/limit-logic/compare-logic/comp_mgtt: D901.2 (A), JP805.1 (A), TP915.1, U902.11 (Q1)
/limit-logic/compare-logic/comp_mstt: D902.2 (A), JP806.1 (A), TP916.1, U902.12 (Q2)
/limit-logic/compare-logic/comp_ucle: D906.2 (A), JP802.1 (A), R1307.2, TP910.1, U1301.1
/limit-logic/compare-logic/comp_uvle: D904.2 (A), JP804.1 (A), R1207.2, TP909.1, U1201.1
/limit-logic/compare-logic/window-comparator1/ule: R1107.2, U902.5 (B1), U1101.1
/limit-logic/compare-logic/window-comparator1/~lle: R1108.2, U901.3, U1101.7
/limit-logic/compare-logic/window-comparator2/~lle: R1208.2, U901.5, U1201.7
/limit-logic/compare-logic/window-comparator3/~lle: R1308.2, U901.9, U1301.7
/limit-logic/compare-logic/window-comparator/ule: R1007.2, U902.4 (A1), U1001.1
/limit-logic/compare-logic/window-comparator/~lle: R1008.2, U901.1, U1001.7
/limit-logic/enable: JP807.2 (B), TP802.1, U802.5 (EN), U803.5 (EN)
/limit-logic/mode-transition/comp_lcle: JP801.2 (B), U1402.4, U1404.1, U1406.5
/limit-logic/mode-transition/comp_lvle: JP803.2 (B), U1403.4, U1404.9, U1406.12
/limit-logic/mode-transition/comp_mgtt: JP805.2 (B), U1405.6, U1405.13
/limit-logic/mode-transition/comp_mstt: JP806.2 (B), U1405.2, U1405.9
/limit-logic/mode-transition/comp_ucle: JP802.2 (B), U1402.12, U1404.3, U1406.1
/limit-logic/mode-transition/comp_uvle: JP804.2 (B), U1403.12, U1404.11, U1406.8
/limit-logic/mode-transition/enable_ok: JP807.1 (A), R1401.1, TP1408.1, U1401.10, U1401.12
/limit-logic/mode-transition/r_mode_cc: JP814.1 (A), TP1414.1, U1408.9
/limit-logic/mode-transition/r_mode_lclc: JP810.1 (A), TP1412.1, U1407.6
/limit-logic/mode-transition/r_mode_lvlc: JP816.1 (A), TP1415.1, U1408.6
/limit-logic/mode-transition/r_mode_uclc: JP812.1 (A), TP1413.1, U1407.10
/limit-logic/mode-transition/r_mode_uvlc: JP818.1 (A), TP1416.1, U1408.10
/limit-logic/mode-transition/r_mode_vc: JP808.1 (A), TP1411.1, U1407.9
/limit-logic/mode-transition/s_mode_cc: JP815.1 (A), TP1410.1, U1401.4
/limit-logic/mode-transition/s_mode_lclc: JP811.1 (A), TP1404.1, U1402.6
/limit-logic/mode-transition/s_mode_lvlc: JP817.1 (A), TP1406.1, U1403.6
/limit-logic/mode-transition/s_mode_uclc: JP813.1 (A), TP1405.1, U1402.10
/limit-logic/mode-transition/s_mode_uvlc: JP819.1 (A), TP1407.1, U1403.10
/limit-logic/mode-transition/s_mode_vc: JP809.1 (A), TP1409.1, U1401.3
/limit-logic/mode-transition/transition_ready: U1401.2, U1401.6, U1401.11, U1402.5, U1402.13, U1403.5, U1403.13
/limit-logic/mode-transition/~comp_lcle: U1402.1, U1404.2, U1405.1
/limit-logic/mode-transition/~comp_lvle: U1403.1, U1404.8, U1405.8
/limit-logic/mode-transition/~comp_ucle: U1402.2, U1404.4, U1405.5
/limit-logic/mode-transition/~comp_uvle: U1403.2, U1404.10, U1405.12
/limit-logic/mode-transition/~enable_ok: Q1401.2 (C), R1402.2, TP1417.1, U1407.5, U1407.8, U1407.13, U1408.5, U1408.8, U1408.13
/limit-logic/mode_cc: D804.2 (A), JP104.1 (A), R803.2, TP806.1, U801.9, U803.2
/limit-logic/mode_lclc: D802.2 (A), JP106.1 (A), R805.2, TP804.1, U801.3, U802.9
/limit-logic/mode_lvlc: D805.2 (A), JP103.1 (A), R802.2, TP807.1, U801.10, U803.9
/limit-logic/mode_uclc: D803.2 (A), JP105.1 (A), R804.2, TP805.1, U801.4, U802.10
/limit-logic/mode_uvlc: D806.2 (A), JP102.1 (A), R801.2, TP808.1, U801.11, U803.10
/limit-logic/mode_vc: D801.2 (A), JP101.1 (A), R806.2, TP803.1, U801.2, U802.2
/limit-logic/r_mode_cc: JP814.2 (B), U803.3
/limit-logic/r_mode_lclc: JP810.2 (B), U802.7
/limit-logic/r_mode_lvlc: JP816.2 (B), U803.7
/limit-logic/r_mode_uclc: JP812.2 (B), U802.11
/limit-logic/r_mode_uvlc: JP818.2 (B), U803.11
/limit-logic/r_mode_vc: JP808.2 (B), U802.3
/limit-logic/s_mode_cc: JP815.2 (B), U803.4
/limit-logic/s_mode_lclc: JP811.2 (B), U802.6
/limit-logic/s_mode_lvlc: JP817.2 (B), U803.6
/limit-logic/s_mode_uclc: JP813.2 (B), U802.12
/limit-logic/s_mode_uvlc: JP819.2 (B), U803.12
/limit-logic/s_mode_vc: JP809.2 (B), U802.4
/limit-logic/~mode: TP801.1, TP1403.1, U801.13, U1401.13
/meas_out_i: JP129.2 (B), R303.2, R1105.1, R1106.1, R1305.1, R1306.1, TP303.1, TP903.1, TP1609.1, U1601.8
/meas_out_v: JP128.2 (B), R203.2, R1005.1, R1006.1, R1205.1, R1206.1, TP203.1, TP901.1, TP1608.1, U1602.8
/measurement/in: JP116.2 (B), U1502.1 (IP+), U1502.2 (IP+)
/measurement/meas_out_i: JP129.1 (A), R1510.1, TP1506.1, U1501.1
/measurement/meas_out_v: JP127.1 (A), JP128.1 (A), TP1501.1, U1502.3 (IP-), U1502.4 (IP-)
/measurement/viout: R1508.2, TP1502.1, U1502.7 (VIOUT)
/measurement/voff: R1502.1, R1504.2, RV1501.3, TP1504.1
/measurement/vzcr: C1503.1, R1503.2, TP1503.1, U1502.6 (VZCR)
/mux/mode_cc: JP104.2 (B), TP1614.1, U1602.13, U1603.3
/mux/mode_lclc: JP106.2 (B), TP1612.1, U1601.12, U1603.4
/mux/mode_lvlc: JP103.2 (B), TP1615.1, U1602.12, U1603.2
/mux/mode_uclc: JP105.2 (B), TP1613.1, U1601.5, U1603.5
/mux/mode_uvlc: JP102.2 (B), TP1616.1, U1602.5, U1603.8
/mux/mode_vc: JP101.2 (B), TP1611.1, U1601.13, U1603.1
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

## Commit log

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2024-05-21 add schematic page settings
    [pss.kicad_sch]
2024-05-21 add hierarchical outstage sheet
    [outstage.kicad_sch, pss.kicad_sch]
2024-05-22 add outstage with emitter follower
    [emitter_follower.kicad_sch, outstage.kicad_sch, pss.kicad_sch]
2024-05-22 add bias stage, add empty MPN property
    [bias.kicad_sch, emitter_follower.kicad_sch, outstage.kicad_sch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]
2024-05-22 schematic version bump 0.1.0
    [bias.kicad_sch, emitter_follower.kicad_sch, outstage.kicad_sch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]
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2024-05-26 change rubber diode vbe multiplier trimmer position
    changed position prohibits excess dropoff voltage in case of machanical failure of trimmer
    [bias.kicad_sch, emitter_follower.kicad_sch, outstage.kicad_sch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]
2024-05-26 fix wrong part number of current limiting transistors in outstage
    [bias.kicad_sch, emitter_follower.kicad_sch, outstage.kicad_sch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]
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2024-09-27 fix ERC error: unconnected pins
    [control.kicad_sch, pss.kicad_sch]
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2024-10-08 fix limit-logic SR latch positiv logic 4043
    4043 is positive logic, not wrongly used 4044
    [limit-logic.kicad_sch]
2024-10-08 fix limit-logic 4043 symbol
    [limit-logic.kicad_sch]
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2024-10-11 add limit-logic pull ups for tristate of mode latches
    [limit-logic.kicad_sch, mode-transition.kicad_sch]
2024-10-11 add limit-logic compare-logic hierachical sheet and hirarchy connectors
    [compare-logic.kicad_sch, limit-logic.kicad_sch, mode-transition.kicad_sch]
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2024-10-25 fix window-comparator accept two limit inputs
    [compare-logic.kicad_sch, window-comparator.kicad_sch]
2024-10-25 add window-comparator multiple instances for all configured limits and refs
    [compare-logic.kicad_sch, window-comparator.kicad_sch]
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2024-10-25 add compare-logic input pull up for unused inverters
    [compare-logic.kicad_sch]
2024-10-25 fix missing footprints, MPN, VPN and datasheet info in BOM
    [bias.kicad_sch, emitter_follower.kicad_sch, mode-transition.kicad_sch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]
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2024-10-28 remove control-logic hierarchical parent sheet
    Sheet is unnecessary for system overview and hides details of the structure, that should be presented.
    Removing the sheet also allows to make a clear separation of the power electronics, controller and measurement for
    multi PCB Layout. This separation would be hidden away with the control-logic super sheet and would cut through
    multiple hierarchical layers.
    [compare-logic.kicad_sch, control-logic.kicad_sch, control.kicad_sch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]
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2024-11-06 change window-comparator quiescent current of schmitt-trigger
    increase the quiescent current of the schmitt trigger by a factor of 10 to avoid usage of 10MOhm resistor
    this will yield a minimum quiescent current of 5µA > 10pA (comparator input bias current)
    [window-comparator.kicad_sch]
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2024-11-07 fix limit-logic mode pull downs
    limit-logic should implement gapping switching between modes to avoid short circuit of active sources
    connected during the transition. The same behavior should be implemented in case of the tri-state output
    of the rs-latch is used. Hence, a pull down (NOT a pull up) is required for the modes.
    [limit-logic.kicad_sch]
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2024-11-07 fix mode-transition to allow transition between limitmodes
    [mode-transition.kicad_sch]
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2024-11-07 add mode-transition missing part number and footprint
    [mode-transition.kicad_sch]
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2024-11-12 add control high impedance input drive
    high impedance input drive is added as substitution for pull ups/downs to define operation when stage is disconnected
    or gapping from the multiplexer is occuring.
    [control.kicad_sch, mux.kicad_sch]
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2024-11-13 fix control difference junction switched inputs
    [control.kicad_sch]
2024-11-13 fix control pid controller circuit
    circuit in Europalehrbuch Tabellenbuch Elektrotechnik which is listed under 'pid controller' is not a pid controller.
    circuit is redesigned as described in docs by designing the pid with RC networks.
    [control.kicad_sch]
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2024-11-14 edit control pid parameters to be ready for 1MHz pole of current sensor
    [control.kicad_sch]
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2024-11-18 fix control sign of reference and measured signal
    [control.kicad_sch]
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2024-11-19 edit window-comparator feedback prof spiegelberg, remove hysteresis at window comparator
    [relay.kicad_sch, window-comparator.kicad_sch]
2024-11-19 edit window-comparator feedback prof spiegelberg, add trimmer to window generation
    [window-comparator.kicad_sch]
2024-11-19 edit bias and measurement to reuse smd trimmer instead of tht trimmer
    [bias.kicad_sch, measurement.kicad_sch]
2024-11-20 edit control feedback from prof spiegelberg, adjust input offset correction resistor
    [control.kicad_sch]
2024-11-21 edit control feedback from prof spiegelberg, make pid control parameters independently adjustable
    [bias.kicad_sch, compare-logic.kicad_sch, control-var.kicad_sch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]
2024-11-21 edit control setting point for KP = 10 at trimmer changed
    changed the fixed resistance, so that the setting for KP = 10 is at 50% turn.
    [control-var.kicad_sch, diode-network.kicad_sch]
2024-11-25 edit control set pid parameters as per controller design of bandwidth limited controller
    [control-var.kicad_sch]
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2024-11-25 fix control missing bandwidth limitation of proportional term
    [bias.kicad_sch, compare-logic.kicad_sch, control-var.kicad_sch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]
2024-11-26 add conf digital to analog converter ad5672r to sub circuit
    [conf.kicad_sch, pss.kicad_sch]
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2024-11-27 edit relay invert input logic
    [pss.kicad_sch, relay.kicad_sch]
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2024-11-28 fix adc lowpass filter frequency
    [adc.kicad_sch, digital-interface.kicad_sch]
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2024-12-02 add leds as visual indicators for internal state
    [compare-logic.kicad_sch, conf.kicad_sch, limit-logic.kicad_sch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]
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2024-12-03 add pss connectors for interfacing with external components
    [digital-interface.kicad_sch, limit-logic.kicad_sch, power-electronics.kicad_sch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]
2024-12-03 edit pss individual power nets for sub circuits
    [adc.kicad_sch, compare-logic.kicad_sch, conf.kicad_sch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]
2024-12-03 pss fix ERC errors bus and hierarchical connection
    [pss.kicad_sch]
2024-12-03 fix digital-interface ERC error wrong connection of ESD diode pins
    [digital-interface.kicad_sch]
2024-12-03 fix pss ERC error unconnected labels
    [conf.kicad_sch, power.kicad_sch, pss.kicad_sch]
2024-12-03 fix pss ERC error: missing power flag
    [adc.kicad_sch, compare-logic.kicad_sch, conf.kicad_sch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]
2024-12-03 fix adc ERC error: missing ground connection for REFGND pin
    [adc.kicad_sch]
2024-12-03 fix pss ERC errors: multiple outputs connected
    [adc.kicad_sch, conf.kicad_sch, control-var.kicad_sch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]
2024-12-03 fix outstage ERC error: fans connected to 24V not 10V
    [outstage.kicad_sch]
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2024-12-04 fix pss missing not connected pins in symbols
    [limit-logic.kicad_sch, pss.kicad_pcb]
2024-12-04 add outstage separation by connectors for individual PCB
    [emitter_follower.kicad_sch, outstage-unit.kicad_sch, outstage.kicad_sch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]
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2024-12-04 edit pss symbol library: export all schematic symbols to library 'pss' and update symbol link
    [adc.kicad_sch, bias.kicad_sch, compare-logic.kicad_sch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]
2024-12-04 edit pss footprint library: export all footprints to library 'pss' and update footprint links
    [adc.kicad_sch, bias.kicad_sch, compare-logic.kicad_sch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]
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2024-12-04 fix pss datasheet links not committed
    [adc.kicad_sch, bias.kicad_sch, compare-logic.kicad_sch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]
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2024-12-05 add control solder jumper to deactivate anti-integral windup
    [control-var.kicad_sch]
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2024-12-07 fix soldermask expansion DRC error for bridging
    [pss.kicad_pcb]
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2024-12-07 add pcb edge cuts outline and NPTH mounting hole for plug-in unit mounting
    [pss.kicad_pcb]
2024-12-07 add pcb edge clearance keepout area
    [pss.kicad_pcb]
2024-12-07 add pcb mounting holes for stacking via M3x60 hexnuts
    [pss.kicad_pcb]
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2024-12-08 add pcb outstage-unit sub circuit layout of power-electronics
    [emitter_follower.kicad_pcb, outstage-unit.kicad_pcb]
2024-12-08 edit outstage connector pin out for outstage-unit
    enhance layout option with other pin out and mirror pinout for second outstage.
    This allows to create a better layout with less crossing of high current tracks.
    [adc.kicad_sch, bias.kicad_sch, compare-logic.kicad_sch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]
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2024-12-08 edit heatsink mounting holes position, fix copper pour
    [emitter_follower.kicad_pcb, outstage-unit.kicad_pcb]
2024-12-08 fix pcb outstage-unit DRC errors
    [outstage-unit.kicad_pcb]
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2024-12-08 fix layout emitter_follower plane overhang prohibits zonefill
    [emitter_follower.kicad_pcb, outstage-unit.kicad_pcb]
2024-12-08 fix pcb outstage-unit copper fill cut by fan power trace
    [outstage-unit.kicad_pcb]
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2024-12-08 fix schematic netlist error, two nets with same name
    [adc.kicad_sch, bias.kicad_sch, compare-logic.kicad_sch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]
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2024-12-08 remove pss solder jumper in output current flow around measurement sub circuit
    [adc.kicad_sch, bias.kicad_sch, compare-logic.kicad_sch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]
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2024-12-09 fix pcb outstage-unit zone priority
    [outstage-unit.kicad_pcb]
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2024-12-09 fix outstage-unit symbol of heatsink, the heatsink is isolated
    [adc.kicad_sch, bias.kicad_sch, compare-logic.kicad_sch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]
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2024-12-10 fix pss lightpipe length variant selection
    [conf.kicad_sch, limit-logic.kicad_sch, relay.kicad_sch]
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2024-12-10 fix bias heatsink unconnected electrical connection
    [adc.kicad_sch, bias.kicad_sch, compare-logic.kicad_sch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]
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2024-12-10 edit digital-interface use bipolar esd diodes for layout
    [adc.kicad_sch, bias.kicad_sch, compare-logic.kicad_sch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]
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2024-12-10 add pcb layout for adc sub circuit as hierarchical layout
    [adc.kicad_pcb]
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2024-12-11 add pcb layout for connection of adc circuit
    [adc.kicad_pcb, adc.kicad_sch, bias.kicad_sch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]
2024-12-12 add pcb layout for conf sub circuit - prototype
    [conf.kicad_sch]
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2024-12-12 add pcb layout for compare-logic sub circuit - prototype
    [window-comparator.kicad_pcb, window-comparator.kicad_sch]
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2024-12-14 fix pcb layout DRC errors
    [adc.kicad_sch, bias.kicad_sch, compare-logic.kicad_sch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]
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2025-01-20 upadte pcb from schematic, fixes drc error for intentionally unconntected heatsink
